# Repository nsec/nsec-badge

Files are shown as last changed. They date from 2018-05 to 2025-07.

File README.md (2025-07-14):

NorthSec 2025 badge
===================

Brought to you by the Team badge of NorthSec.

## Overview

<p align="center">
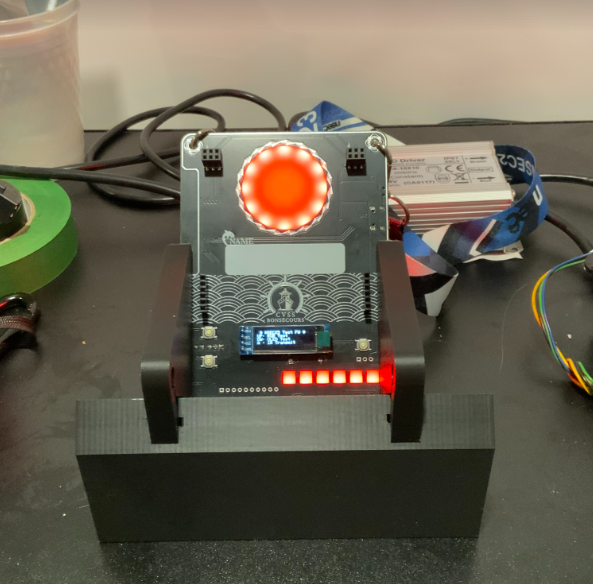
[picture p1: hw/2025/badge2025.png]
   <br>
</p>

## Hardware

The NorthSec 2025 badge is loosely based on the ESP32-C3 design with an
[ESP32-C3 microcontroller](https://www.espressif.com/en/products/socs/esp32-c3)
(ESP32-C3-WROOM-02-N4) which is used to drive several periphery devices:

- Eighteen [NeoPixel](https://en.wikipedia.org/wiki/Adafruit_Industries#NeoPixel) RGB LEDs
- Five buttons
- One IR 'pairing' connector
- Two [Shitty Add-On V1.69bis](https://hackaday.com/2019/03/20/introducing-the-shitty-add-on-v1-69bis-standard/) connector

The badge is powered through a USB-C port or through 3 AAA batteries.

If you wish to hack your badge or create a new one based on the hardware. All
the information [is available here](hw/2025/).

## Building the firmware

The firmware is based on the [Espressif IoT Development
Framework](https://docs.platformio.org/en/latest/frameworks/espidf.html). The
build system uses
[PlatformIO](https://docs.platformio.org/en/stable/what-is-platformio.html) to
easily manage the dependencies.

You can install it on Debian / Ubuntu in a python virtualenv with these
commands:

```bash
sudo apt install python3-virtualenv

virtualenv .venv
. .venv/bin/activate

pip install platformio
```

The installation procedure for your OS may differ a little, please consult the
[PlatformIO
documentation](https://docs.platformio.org/en/stable/core/installation/index.html)
if you have any difficulties.

Once the installation is complete you can build the firmware:

```bash
# Conference firmware
pio run -e conference

# CTF firmware
pio run -e ctf
```

## Flashing

Flash the firmware with this command:

```bash
# Conference firmware
pio run -t upload -e conference

# CTF firmware
pio run -t upload -e ctf
```

If multiple badges are connected, you can select which badge will be flash with
the `--upload-port <port_name>` option:

```bash
# Conference firmware
pio run -t upload -e conference --upload-port <port_name>
```

To improve the upload speed, you can skip the build validation/process with the
`-t nobuild` option:

```bash
# Conference firmware
pio run -t upload -t nobuild -e conference
```

## Debugging

To read the logging statements output on the USB serial interface, it is
possible to use `pio device monitor` or `idf.py`'s `monitor` command.

However, you can use your preferred terminal emulator by pointing it to the
`/dev/ttyACM0` device. The badge is configured to output at `115200` bauds,
without parity, and with one stop bit per character.

Note that electrically resetting the board using the hardware switch will cause
the pseudo-terminal device to disappear, making it hard to read the logs
emitted during boot.

Pulsing the DTR signal (lowering it for 1 second) will cause the board to reset
without affecting the pseudo-terminal device, allowing you to read early-boot
messages. This is supported by most terminal emulators.

## Credits
NorthSec CTF badge 2025 is brought to you by the teamwork of:

 - [abdelq](https://github.com/abdelq)
 - [IterateMe](https://github.com/IterateMe)
 - [lle](https://github.com/lle)
 - [nyx0](https://github.com/nyx0)
 - [p0ns](https://github.com/p0ns)
 - [padraignix](https://github.com/padraignix)
 - [Svieg](https://github.com/Svieg)
 - [sylemieux](https://github.com/sylemieux)
 - [TheKGBSpy](https://github.com/TheKGBSpy)
 - [mjeanson](https://github.com/mjeanson)

Special thanks to:
 - [20th](https://github.com/20th)
 - [jgalar](https://github.com/jgalar)

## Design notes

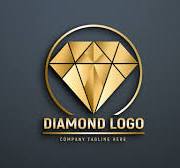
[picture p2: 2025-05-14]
hw/2025/sao/Sao_SlotMachine_v2/DiamondArt.jpg

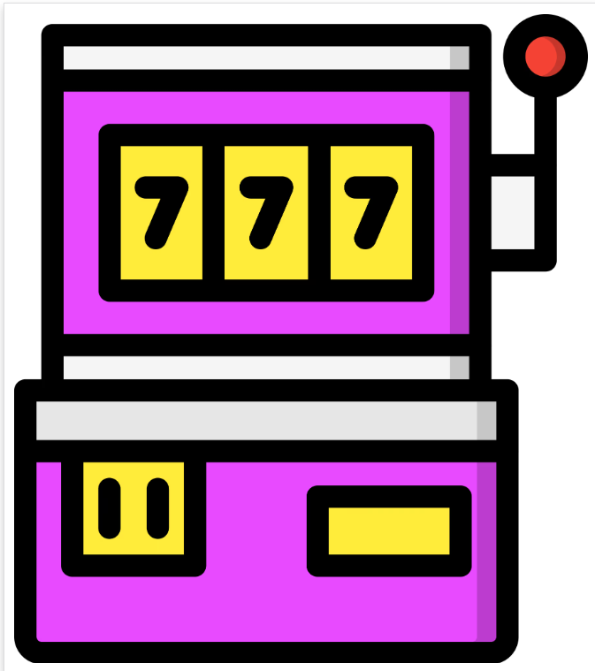
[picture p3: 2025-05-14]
hw/2025/sao/Sao_SlotMachine/image.png

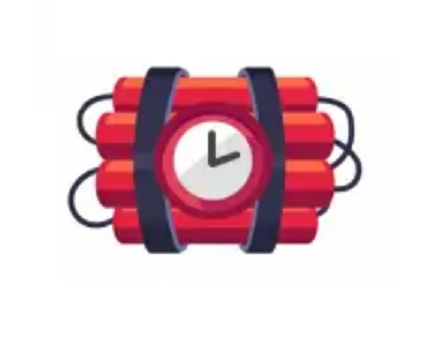
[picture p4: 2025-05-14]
hw/2025/sao/Sao_Bomb/Untitled.png

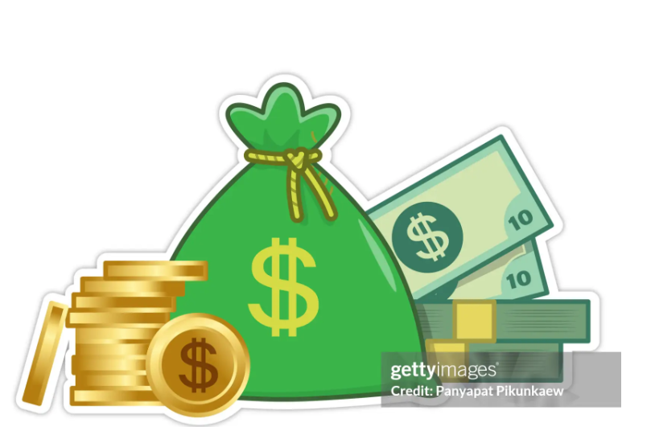
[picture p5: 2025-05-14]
hw/2025/sao/Sao_CashBag/Untitled.png

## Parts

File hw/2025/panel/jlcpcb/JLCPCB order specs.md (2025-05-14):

- Base Material: FR-4
- Layers: 2
- Dimensions: Auto
- Panel Qty: 5
- Product Type: Industrial/Consumer Electronics

## PCB Specifications
- Different design: 1
- Delivery format: Panel by Customer
- Panel Format: Column:2 Row:2 
- PCB Thickness: 1.6mm
- PCB Color: Black
- Silkscreen: White
- Surface Finish: ENIG
- Gold Thickness: 1 U''

## High-spec Options
- Outer Copper Weight: 1 oz
- Via Covering: Tented
- Min via hole size/diameter: 0.3mm/(0.4/0.45mm)
- Board Outline Tolerance: +-0.2mm(Regular)
- Confirm Production File: Yes
- Mark on PCB: 2D Barcode (Serial Number)
	- Printing: 2D barcode only
	- Code Type: Data Matrix Code
	- Serial Number Setting: 
		- Prefix: NSEC
		- Unique Number: leave as is
		- Incrementing number: 0001 (as is)
		- 2D barcode size: 5 * 5mm
		- 2D barcode position: Specify position
- Electrical Test: Flying Probe Fully Test
- Gold Fingers: Yes
- 30°finger chamfered: Yes
- Castellated Holes: No
- Edge Plating: No

## PCB Assembly
- PCBA Type: Standard
- Assembly Type: Both Sides
- PCBA Qty: 5
- Edge Rails/Fiducials: Added by Customer
- Confirm Parts Placement: yes
- Parts Selection: By Customer

## Advanced Options:
- Photo Confirmation: No
- Board Cleaning: No
- Conformal Coating: No
- Bake Components: No
- Packaging: Antistatic bubble film
- Depanel boards & edge rail before delivery: Yes
- Solder paste: Sn96.5%, Ag3.0%, Cu0.5%
- Add paste for unpopulated pad & step stencil opening: No
- Flying Probe Test: No
- Nitrogen Reflow Soldering: No
- Others: No

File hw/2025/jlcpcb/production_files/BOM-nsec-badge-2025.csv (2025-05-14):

Comment | Designator | Footprint | LCSC | Quantity
SSSS811101 | KEY1 | SW-SMD_SSSS811101 | C109335 | 1
MMBT3904 | Q1 | SOT-23 | C111113 | 1
MBR120LSF | D1,D2 | SOD-123_L2.8-W1.8-LS3.7-RD | C130880 | 2
0.1uF | C10,C11,C12,C13,C14,C15,C16,C20,C21,C22,C23,C24,C25,C5,C6,C7,C8,C9 | C_0603_1608Metric | C14663 | 18
1uF | C1,C17,C3,C4 | C_0603_1608Metric | C15849 | 4
10uF | C18,C2 | C_0805_2012Metric | C15850 | 2
TYPE-C-31-M-12 | U2 | USB-C_SMD-TYPE-C-31-M-12 | C165948 | 1
1K | R12 | R_0603_1608Metric | C21190 | 1
470 | R10 | R_0603_1608Metric | C23179 | 1
5.1K | R2,R3,R4,R5 | R_0603_1608Metric | C23186 | 4
56 | R11 | R_0603_1608Metric | C25196 | 1
100K | R1,R13 | R_0603_1608Metric | C25803 | 2
10K | R14,R6,R7,R8,R9 | R_0603_1608Metric | C25804 | 5
0.1uF | C19 | C_0805_2012Metric | C28233 | 1
ESP32-C3-WROOM-02-N4(4MB) | U1 | BULETM-SMD_ESPRESSIF_ESP32-C3-WROOM-02-N4-4MB | C2934560 | 1
TS-1187A-B-A-B | SW1,SW2,SW3,SW4 | SW-SMD_4P-L5.1-W5.1-P3.70-LS6.5-TL_H1.5 | C318884 | 4
PM254-2-03-S-8_5 | J1,J2 | HDR-SMD_6P-P2.54-V-F-R2-C3-LS7.0 | C3975148 | 2
Conn_01x06 | J6,J7 | PinSocket_1x06_P2.54mm_Vertical | C40877 | 2
TSOP34838 | U5 | SENSOR-TH_TSOP34838 | C44620 | 1
IR968-8C | U4 | LED-TH_L2.9-W2.9-P2.54-FD | C475375 | 1
AP2112K-3_3TRG1 | U6 | SOT-25-5_L2.9-W1.6-P0.95-LS2.8-BL | C51118 | 1
HS96L03W2C03 | U7 | OLED-TH_L38.0-W12.0_HS91L02W2C01 | C5248081 | 1
2479 | BT1 | BAT_2479 | C5370880 | 1
SK6812SIDE-A_C5378721 | RGB1,RGB10,RGB11,RGB12,RGB13,RGB14,RGB15,RGB16,RGB17,RGB18,RGB2,RGB3,RGB4,RGB5,RGB6,RGB7,RGB8,RGB9 | LED-SMD_SK6812SIDE-A_C5378721 | C5378721 | 18
TPSMF05CT1G | U3 | SOT-363_L2.0-W1.3-P0.65-LS2.1-BL | C558443 | 1
Fuse_Small | F1 | Fuse_1206_3216Metric_Pad1.42x1.75mm_HandSolder | C70065 | 1
FC-2012HRK-620D | LED1,LED2 | LED0805-R-RD | C84256 | 2

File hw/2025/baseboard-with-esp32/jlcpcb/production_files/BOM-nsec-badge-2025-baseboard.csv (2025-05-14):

Comment | Designator | Footprint | LCSC | Quantity
SSSS811101 | KEY1,KEY2 | SW-SMD_SSSS811101 | C109335 | 2
MBR120LSF | D1,D2,D3,D5 | SOD-123_L2.8-W1.8-LS3.7-RD | C130880 | 4
XT4054K421MR-G | U8 | SOT-23-5_L3.0-W1.7-P0.95-LS2.8-BL | C141405 | 1
0.1uF | C5 | C_0603_1608Metric | C14663 | 1
1uF | C1,C3,C6,C9 | C_0603_1608Metric | C15849 | 4
10uF | C2,C4,C8 | C_0805_2012Metric | C15850 | 3
TYPE-C-31-M-12 | U3 | USB-C_SMD-TYPE-C-31-M-12 | C165948 | 1
4.7uF | C7 | C_0805_2012Metric | C1779 | 1
1K | R12,R7,R8,R9 | R_0603_1608Metric | C21190 | 4
WS2812B | D4 | LED_WS2812B_PLCC4_5.0x5.0mm_P3.2mm | C22461793 | 1
390K | R10 | R_0603_1608Metric | C23150 | 1
5.1K | R1,R3,R4,R5 | R_0603_1608Metric | C23186 | 4
100K | R11,R2 | R_0603_1608Metric | C25803 | 2
10K | R6 | R_0603_1608Metric | C25804 | 1
Bus_PCI_32bit_Universal | J5 | CONN-TH_EH06003-DAW-DF | C2761459 | 1
LTST-S220KRKT | LED1,LED2,LED3,LED4 | LED-SMD_L2.2-W1.0-RD_RED-SIDE | C284935 | 4
ESP32-S3-WROOM-1 | U1 | ESP32-S3-WROOM-1 | C2913204 | 1
AP2112K-3_3TRG1 | U2 | SOT-25-5_L2.9-W1.6-P0.95-LS2.8-BL | C51118 | 1
TPSMF05CT1G | U4 | SOT-363_L2.0-W1.3-P0.65-LS2.1-BL | C558443 | 1
XDWF-0920-02P | U7 | CONN-SMD_XDWF-0920-02P | C7527581 | 1
K2-1102SP-Z4SC-04 | U9 | KEY-SMD_4P-L6.0-W6.0-P4.50-LS9.0 | C879736 | 1
GT-TC018A-H0375-L1 | U5,U6 | SW-SMD_L4.7-W3.5-P3.35-EH | C963235 | 2

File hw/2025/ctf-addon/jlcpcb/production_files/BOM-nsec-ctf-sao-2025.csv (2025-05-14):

Comment | Designator | Footprint | LCSC | Quantity
MMBT3906 | U1 | SOT-23-3_L3.0-W1.7-P0.95-LS2.9-BR | C111114 | 1
MBR120LSF | D10 | SOD-123_L2.8-W1.8-LS3.7-RD | C130880 | 1
1 | R6 | R_1206_3216Metric_Pad1.30x1.75mm_HandSolder | C1409 | 1
10K | R10,R9 | R_0805_2012Metric_Pad1.20x1.40mm_HandSolder | C17414 | 2
75 | R1,R2,R3,R4,R5,R7,R8 | R_1206_3216Metric_Pad1.30x1.75mm_HandSolder | C17987 | 7
LED | D1,D2,D3,D4,D5,D6,D7,D8 | LED_1206_3216Metric_Pad1.42x1.75mm_HandSolder | C965822 | 8

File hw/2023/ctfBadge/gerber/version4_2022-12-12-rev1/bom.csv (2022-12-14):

Qty | Value | Device | Package | Parts | JLCPCB | DIGIKEY
22 | 0.1uF | C-EUC0603 | C0603 | C1, C2, C3, C4, C5, C6, C7, C9, C10, C11, C12, C13, C14, C15, C16, C17, C19, C20, C21, C22, C23, C24 | C14663
3 | 100K | RESISTOR_0603_NOOUT | 0603-NO | R1, R3, R7 | C25803
3 | 10201020_KEY | 10201020_KEY | 1020_KEY | U27, U28, U29 |  | 36-1020-ND
3 | 10K | RESISTOR_0603_NOOUT | 0603-NO | R5, R6, R8 | C25804
2 | 10uF | CAP_CERAMIC0805-NOOUTLINE | 0805-NO | C27, C30 | C440198
3 | 1K | RESISTOR_0603_NOOUT | 0603-NO | R10, R13, R14 | C21190
3 | 1uF | CAP_CERAMIC0603_NO | 0603-NO | C8, C26, C31 | C15849
2 | 470 | RESISTOR_0603_NOOUT | 0603-NO | R9, R11 | C114669
2 | 5.1K | RESISTOR_0603_NOOUT | 0603-NO | R2, R4 | C23186
1 | AP2112-3.3 | VREG_SOT23-5 | SOT23-5 | U2 | C150742
1 | CH340C | CH340C | SOIC127P600X180-16N | U1 | C84681
1 | ESP32_WROOM32_SKINNY | ESP32_WROOM32_SKINNY | WROOM32_SKINNY | X2 | C82899
1 | KMR2 | SWITCH_TACT_SMT4.6X2.8 | BTN_KMR2_4.6X2.8 | SW2 | C269272
2 | MBR120 | DIODE-SCHOTTKYSOD-123 | SOD-123 | D2, D6 | C130880
1 | PCM12SMTRPCM12SMTR_CNK | PCM12SMTRPCM12SMTR_CNK | PCM12SMTR_CNK | U5 |  | 401-2016-2-ND
3 | RED | LED0805_NOOUTLINE | CHIPLED_0805_NOOUTLINE | D1, D3, D5 | C84256
1 | SMF05CT1G | SMF05CT1G | SOT65P210X110-6N | U4 | C558443
1 | SSW-103-22-F-D-VS-K-TRCON3_SSW-D-DUMZ_HDR_SAI | SSW-103-22-F-D-VS-K-TRCON3_SSW-D-DUMZ_HDR_SAI | CON3_SSW-D-DUMZ_HDR_SAI | J2 |  | 952-3251-ND
1 | TYPE-C-31-M-12 | TYPE-C-31-M-12 | HRO_TYPE-C-31-M-12 | J3 | C165948
21 | WS2812-2020 | WS2812-2020 | LED_WS2812-2020 | U6, U7, U8, U9, U10, U11, U12, U13, U14, U15, U16, U17, U18, U19, U20, U21, U22, U23, U24, U25, U26 | C965555
2 | mmbt2222 | TRANSISTOR_NPNSOT23-3 | SOT23-3 | Q1, Q2 | C8512

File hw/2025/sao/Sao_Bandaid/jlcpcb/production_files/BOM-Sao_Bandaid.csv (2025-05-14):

Comment | Designator | Footprint | LCSC | Quantity
SAO Connector SMD | J1 | SAO Connector SMD |  | 1
1K | R3 | R_1206_3216Metric_Pad1.30x1.75mm_HandSolder |  | 1
1K | R2 | R_1206_3216Metric_Pad1.30x1.75mm_HandSolder |  | 1
330 | R1 | R_1206_3216Metric_Pad1.30x1.75mm_HandSolder |  | 1
LED | D1 | LED_1206_3216Metric_Pad1.42x1.75mm_HandSolder |  | 1

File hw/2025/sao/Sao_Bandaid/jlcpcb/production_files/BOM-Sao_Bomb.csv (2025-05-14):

Comment | Designator | Footprint | LCSC | Quantity
330 | R4 | R_1206_3216Metric_Pad1.30x1.75mm_HandSolder |  | 1
330 | R2 | R_1206_3216Metric_Pad1.30x1.75mm_HandSolder |  | 1
330 | R3 | R_1206_3216Metric_Pad1.30x1.75mm_HandSolder |  | 1
330 | R1 | R_1206_3216Metric_Pad1.30x1.75mm_HandSolder |  | 1
LED | D3 | LED_1206_3216Metric_Pad1.42x1.75mm_HandSolder |  | 1
LED | D4 | LED_1206_3216Metric_Pad1.42x1.75mm_HandSolder |  | 1
LED | D1 | LED_1206_3216Metric_Pad1.42x1.75mm_HandSolder |  | 1
LED | D2 | LED_1206_3216Metric_Pad1.42x1.75mm_HandSolder |  | 1
Conn_01x01_Socket |  | PinSocket_1x01_P1.27mm_Vertical |  | 0
Conn_01x01_Socket |  | PinSocket_1x01_P1.27mm_Vertical |  | 0
Conn_01x01_Socket |  | PinSocket_1x01_P1.27mm_Vertical |  | 0
Conn_01x01_Socket |  | PinSocket_1x01_P1.27mm_Vertical |  | 0
Conn_01x01_Socket |  | PinSocket_1x01_P1.27mm_Vertical |  | 0
Conn_01x01_Socket |  | PinSocket_1x01_P1.27mm_Vertical |  | 0
Conn_01x01_Socket |  | PinSocket_1x01_P1.27mm_Vertical |  | 0
Conn_01x01_Socket |  | PinSocket_1x01_P1.27mm_Vertical |  | 0
SAO Connector SMD | J1 | SAO Connector SMD |  | 1

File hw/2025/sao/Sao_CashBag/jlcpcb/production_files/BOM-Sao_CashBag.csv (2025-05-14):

Comment | Designator | Footprint | LCSC | Quantity
LED | D2 | LED_1206_3216Metric_Pad1.42x1.75mm_HandSolder |  | 1
LED | D3 | LED_1206_3216Metric_Pad1.42x1.75mm_HandSolder |  | 1
LED | D1 | LED_1206_3216Metric_Pad1.42x1.75mm_HandSolder |  | 1
330 | R1 | R_1206_3216Metric_Pad1.30x1.75mm_HandSolder |  | 1
330 | R2 | R_1206_3216Metric_Pad1.30x1.75mm_HandSolder |  | 1
330 | R3 | R_1206_3216Metric_Pad1.30x1.75mm_HandSolder |  | 1
SAO Connector SMD | J1 | SAO Connector SMD |  | 1

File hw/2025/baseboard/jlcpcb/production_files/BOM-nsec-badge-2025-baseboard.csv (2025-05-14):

Comment | Designator | Footprint | LCSC | Quantity
Bus_PCI_32bit_Universal | J5 | CONN-TH_EH06003-DAW-DF | C2761459 | 1
Conn_01x02_Socket |  | PinSocket_1x02_P2.54mm_Vertical |  | 0
Conn_01x15_Socket |  | PinSocket_1x15_P2.54mm_Vertical |  | 0
Conn_01x02_Socket |  | PinSocket_1x02_P2.54mm_Vertical |  | 0
Conn_01x02_Socket |  | PinSocket_1x02_P2.54mm_Vertical |  | 0
Conn_01x08_Socket |  | PinHeader_1x08_P2.54mm_Vertical |  | 0
Conn_01x02_Socket |  | PinSocket_1x02_P2.54mm_Vertical |  | 0

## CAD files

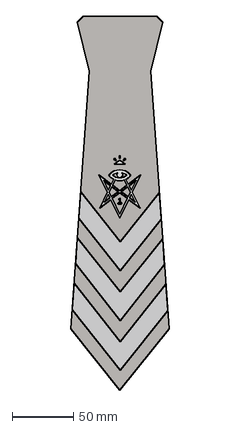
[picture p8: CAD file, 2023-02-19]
hw/2023/ctfBadge/design/badgeCTF2023-01.dxf
79.9 x 304.7 mm

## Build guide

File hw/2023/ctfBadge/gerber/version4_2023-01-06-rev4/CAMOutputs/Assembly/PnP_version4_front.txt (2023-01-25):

C1	-29.00	-230.00	270.00	0.1uF	C0603
C10	27.00	-210.00	270.00	0.1uF	C0603
C11	-23.00	-256.00	270.00	0.1uF	C0603
C12	-27.00	-210.00	270.00	0.1uF	C0603
C13	23.00	-256.00	270.00	0.1uF	C0603
C14	25.00	-190.00	270.00	0.1uF	C0603
C15	-25.00	-190.00	270.00	0.1uF	C0603
C16	23.00	-170.00	270.00	0.1uF	C0603
C17	-22.00	-170.00	270.00	0.1uF	C0603
C19	21.00	-150.00	270.00	0.1uF	C0603
C2	-17.00	-110.00	270.00	0.1uF	C0603
C20	-19.50	-150.00	270.00	0.1uF	C0603
C21	19.00	-130.00	270.00	0.1uF	C0603
C22	-18.00	-130.00	270.00	0.1uF	C0603
C23	0.00	-292.00	0.00	0.1uF	C0603
C24	17.00	-110.00	270.00	0.1uF	C0603
C26	-16.51	-19.69	0.00	1uF	0603-NO
C27	-11.43	-20.96	180.00	10uF	0805-NO
C3	15.00	-90.00	270.00	0.1uF	C0603
C30	-10.79	-3.81	90.00	10uF	0805-NO
C31	-4.45	-36.83	270.00	1uF	0603-NO
C4	-15.00	-90.00	270.00	0.1uF	C0603
C5	14.00	-70.00	270.00	0.1uF	C0603
C6	29.00	-230.00	270.00	0.1uF	C0603
C7	-14.00	-70.00	270.00	0.1uF	C0603
C8	-11.43	-16.51	90.00	1uF	0603-NO
C9	8.89	-26.67	90.00	0.1uF	C0603
D1	-15.88	-5.08	90.00	RED	CHIPLED_0805_NOOUTLINE
D2	-13.97	-25.40	270.00	MBR120	SOD-123
D3	-5.71	-24.77	0.00	RED	CHIPLED_0805_NOOUTLINE
D5	-13.34	-36.83	90.00	RED	CHIPLED_0805_NOOUTLINE
D6	-16.51	-25.40	270.00	MBR120	SOD-123
J2	0.64	-62.23	210.00	SSW-103-22-F-D-VS-K-TRCON3_SSW-D-DUMZ_HDR_SAI	CON3_SSW-D-DUMZ_HDR_SAI
J3	-18.89	-31.24	284.00	TYPE-C-31-M-12	HRO_TYPE-C-31-M-12
Q1	21.54	-34.93	90.00	mmbt2222	SOT23-3
Q2	22.28	-30.48	270.00	mmbt2222	SOT23-3
R1	-10.79	-10.16	180.00	100K	0603-NO
R10	-3.81	-24.77	270.00	1K	0603-NO
R11	12.70	-6.99	0.00	470	0603-NO
R13	-17.14	-38.10	180.00	5.1K	0603-NO
R14	-15.88	-3.18	0.00	5.1K	0603-NO
R2	-13.34	-34.93	0.00	5.1K	0603-NO
R3	-10.79	-12.07	0.00	100K	0603-NO
R4	-13.34	-33.02	0.00	5.1K	0603-NO
R5	17.14	-33.02	180.00	10K	0603-NO
R6	17.14	-36.20	0.00	10K	0603-NO
R7	-13.34	-16.51	270.00	100K	0603-NO
R8	17.14	-38.10	0.00	10K	0603-NO
R9	12.70	-8.89	0.00	470	0603-NO
SW2	0.00	-36.83	180.00	KMR2	BTN_KMR2_4.6X2.8
U1	8.89	-33.02	270.00	CH340C	SOIC127P600X180-16N
U10	-22.00	-110.00	180.00	WS2812-2020	LED_WS2812-2020
U11	22.00	-110.00	180.00	WS2812-2020	LED_WS2812-2020
U12	-24.00	-130.00	180.00	WS2812-2020	LED_WS2812-2020
U13	24.00	-130.00	180.00	WS2812-2020	LED_WS2812-2020
U14	-26.00	-150.00	180.00	WS2812-2020	LED_WS2812-2020
U15	26.00	-150.00	180.00	WS2812-2020	LED_WS2812-2020
U16	-28.00	-170.00	180.00	WS2812-2020	LED_WS2812-2020
U17	28.00	-170.00	180.00	WS2812-2020	LED_WS2812-2020
U18	-30.00	-190.00	180.00	WS2812-2020	LED_WS2812-2020
U19	30.00	-190.00	180.00	WS2812-2020	LED_WS2812-2020
U2	-16.51	-16.51	90.00	AP2112-3.3	SOT23-5
U20	-32.00	-210.00	180.00	WS2812-2020	LED_WS2812-2020
U21	32.00	-210.00	180.00	WS2812-2020	LED_WS2812-2020
U22	-34.00	-230.00	180.00	WS2812-2020	LED_WS2812-2020
U23	34.00	-230.00	180.00	WS2812-2020	LED_WS2812-2020
U24	-28.00	-256.00	180.00	WS2812-2020	LED_WS2812-2020
U25	28.00	-256.00	180.00	WS2812-2020	LED_WS2812-2020
U26	0.00	-287.00	180.00	WS2812-2020	LED_WS2812-2020
U4	17.14	-30.48	180.00	SMF05CT1G	SOT65P210X110-6N
U6	-18.00	-70.00	180.00	WS2812-2020	LED_WS2812-2020
U7	18.00	-70.00	180.00	WS2812-2020	LED_WS2812-2020
U8	-20.00	-90.00	180.00	WS2812-2020	LED_WS2812-2020
U9	20.00	-90.00	180.00	WS2812-2020	LED_WS2812-2020
X2	0.36	-11.71	0.00	ESP32_WROOM32_SKINNY	WROOM32_SKINNY

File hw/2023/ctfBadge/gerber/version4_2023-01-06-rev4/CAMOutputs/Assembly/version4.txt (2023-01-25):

Partlist exported from C:/Users/lambert/Documents/GitHub/nsec-badge-dev/hw/2023/ctfBadge/version4.sch at 2023-01-06 4:14 PM

Qty Value                                         Device                                        Package                 Parts                                                                                                Description                                                                              AVAILABILITY COPYRIGHT                                                DESCRIPTION                                                                DIGI-KEY_PART_NUMBER_1 DIGI-KEY_PART_NUMBER_2 DIGI-KEY_PART_NUMBER_3 DIGI-KEY_PART_NUMBER_4 DIGI-KEY_PART_NUMBER_5 MANUFACTURER              MANUFACTURER_PART_NUMBER MAXIMUM_PACKAGE_HEIGHT MF               MFR_NAME             MP          PACKAGE                  PARTREV    POPULARITY PRICE PURCHASE-URL                                               SNAPEDA_PN     STANDARD                     TP_SIGNAL_NAME
22  0.1uF                                         C-EUC0603                                     C0603                   C1, C2, C3, C4, C5, C6, C7, C9, C10, C11, C12, C13, C14, C15, C16, C17, C19, C20, C21, C22, C23, C24 CAPACITOR, European symbol                                                                                                                                                                                                                                                                                                                                                                                                                                                                                                                                                                                                                                         
3   100K                                          RESISTOR_0603_NOOUT                           0603-NO                 R1, R3, R7                                                                                           Resistors                                                                                                                                                                                                                                                                                                                                                                                                                                                                                                                                                                                                                                                          
3   10201020_KEY                                  10201020_KEY                                  1020_KEY                U27, U28, U29                                                                                                                                                                                              Copyright (C) 2022 Ultra Librarian. All rights reserved.                                                                            1020K-ND               1528-2635-ND           290-1966-ND            2991-1020-ND           36-1020-ND                                       1020                                                             Keystone Electronics                                                                                                                                                                                       
3   10K                                           RESISTOR_0603_NOOUT                           0603-NO                 R5, R6, R8                                                                                           Resistors                                                                                                                                                                                                                                                                                                                                                                                                                                                                                                                                                                                                                                                          
2   10uF                                          CAP_CERAMIC0805-NOOUTLINE                     0805-NO                 C27, C30                                                                                             Ceramic Capacitors                                                                                                                                                                                                                                                                                                                                                                                                                                                                                                                                                                                                                                                 
1   1K                                            RESISTOR_0603_NOOUT                           0603-NO                 R10                                                                                                  Resistors                                                                                                                                                                                                                                                                                                                                                                                                                                                                                                                                                                                                                                                          
3   1uF                                           CAP_CERAMIC0603_NO                            0603-NO                 C8, C26, C31                                                                                         Ceramic Capacitors                                                                                                                                                                                                                                                                                                                                                                                                                                                                                                                                                                                                                                                 
2   470                                           RESISTOR_0603_NOOUT                           0603-NO                 R9, R11                                                                                              Resistors                                                                                                                                                                                                                                                                                                                                                                                                                                                                                                                                                                                                                                                          
4   5.1K                                          RESISTOR_0603_NOOUT                           0603-NO                 R2, R4, R13, R14                                                                                     Resistors                                                                                                                                                                                                                                                                                                                                                                                                                                                                                                                                                                                                                                                          
1   AP2112-3.3                                    VREG_SOT23-5                                  SOT23-5                 U2                                                                                                   SOT23-5 Fixed Voltage Regulators                                                                                                                                                                                                                                                                                                                                                                                                                                                                                                                                                                                                                                   
1   CH340C                                        CH340C                                        SOIC127P600X180-16N     U1                                                                                                   USB to serial chip CH340    Check prices                                                 Not in stock                                                           USB to serial chip CH340                                                                                                                                                                                                                                               WCH                                   CH340C      None                                           None                                                                                                                       
1   ESP32_WROOM32_SKINNY                          ESP32_WROOM32_SKINNY                          WROOM32_SKINNY          X2                                                                                                                                                                                                                                                                                                                                                                                                                                                                                                                                                                                                                                                                                                                                                                      
1   KMR2                                          SWITCH_TACT_SMT4.6X2.8                        BTN_KMR2_4.6X2.8        SW2                                                                                                  SMT Tact Switches                                                                                                                                                                                                                                                                                                                                                                                                                                                                                                                                                                                                                                                  
2   MBR120                                        DIODE-SCHOTTKYSOD-123                         SOD-123                 D2, D6                                                                                                                                                                                                                                                                                                                                                                                                                                                                                                                                                                                                                                                                                                                                                                  
1   PCM12SMTRPCM12SMTR_CNK                        PCM12SMTRPCM12SMTR_CNK                        PCM12SMTR_CNK           U5                                                                                                                                                                                                         Copyright (C) 2022 Ultra Librarian. All rights reserved.                                                                            401-2016-2-ND          401-2016-1-ND          401-2016-6-ND          2266-PCM12SMTR-ND                                                       PCM12SMTR                                                        C&K                                                                                                                                                                                                        
4   PTR1B1,27                                     PTR1B1,27                                     B1,27                   TP1, TP2, TP3, TP4                                                                                   TEST PIN                                                                                                                                                                                                                                                                                                                                                                                                                                                                                                                     2                                                                                                                                     
3   RED                                           LED0805_NOOUTLINE                             CHIPLED_0805_NOOUTLINE  D1, D3, D5                                                                                           LED                                                                                                                                                                                                                                                                                                                                                                                                                                                                                                                                                                                                                                                                
1   SMF05CT1G                                     SMF05CT1G                                     SOT65P210X110-6N        U4                                                                                                   SMF05C Series 7.2 V 100 W 5-Line Transient Voltage Suppressor Array - SC-88 Check prices In Stock                                                               12.5V Clamp 8A (8/20µs) Ipp Tvs Diode Surface Mount SC-88/SC70-6/SOT-363                                                                                                                                                                                               ON Semiconductor                      SMF05CT1G   SC-88-6 ON Semiconductor                       None  https://pricing.snapeda.com/search/part/SMF05CT1G/?ref=eda                                                           
1   SSW-103-22-F-D-VS-K-TRCON3_SSW-D-DUMZ_HDR_SAI SSW-103-22-F-D-VS-K-TRCON3_SSW-D-DUMZ_HDR_SAI CON3_SSW-D-DUMZ_HDR_SAI J2                                                                                                                                                                                                         Copyright (C) 2022 Ultra Librarian. All rights reserved.                                                                            SAM14622CT-ND          SAM14622DKR-ND         SAM14622TR-ND                                                                                  SSW-103-22-F-D-VS-K-TR                                           Samtec Inc                                                                                                                                                                                                 
1   TYPE-C-31-M-12                                TYPE-C-31-M-12                                HRO_TYPE-C-31-M-12      J3                                                                                                                                                                                                                                                                                                                                                                                                                                                                HRO Electronics Co., Ltd.                          3.26 mm                                                                                           2020.12.08                                                                             TYPE-C-31-M-12 Manufacturer Recommendations               
21  WS2812-2020                                   WS2812-2020                                   LED_WS2812-2020         U6, U7, U8, U9, U10, U11, U12, U13, U14, U15, U16, U17, U18, U19, U20, U21, U22, U23, U24, U25, U26  Intelligent control LED                                                                  Not in stock                                                           Intelligent control LED light source, SMD-4                                                                                                                                                                                                                            Worldsemi                             WS2812-2020 Package                                        None                                                                                                                       
2   mmbt2222                                      TRANSISTOR_NPNSOT23-3                         SOT23-3                 Q1, Q2                                                                                               Transistor NPN

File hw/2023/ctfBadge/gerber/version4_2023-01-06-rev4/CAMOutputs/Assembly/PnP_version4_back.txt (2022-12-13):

TP1	17.14	-13.97	0.00	PTR1B1,27	B1,27
TP2	17.14	-12.07	0.00	PTR1B1,27	B1,27
TP3	17.14	-10.16	0.00	PTR1B1,27	B1,27
TP4	17.14	-8.26	0.00	PTR1B1,27	B1,27
U27	-15.24	-237.49	270.00	10201020_KEY	1020_KEY
U28	0.00	-237.49	90.00	10201020_KEY	1020_KEY
U29	15.24	-237.49	270.00	10201020_KEY	1020_KEY
U5	-23.25	-57.53	185.00	PCM12SMTRPCM12SMTR_CNK	PCM12SMTR_CNK

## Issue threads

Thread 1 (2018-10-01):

Leak

obilodeau, 2018-10-01:
https://github.com/nsec/nsec-badge/blob/7a2f7601874b1e2cf20599a2e3ec0ffa3dc4f5e5/nrf52/led_code_storage.h#L45

:open_mouth:

marc-etienne, 2018-10-01:
nsec18 is finished
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

cashew22, 2018-10-01:
Hahahahaa

Closed 2018-10-01.

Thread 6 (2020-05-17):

Leak 2019

obilodeau, 2020-05-17:
https://github.com/nsec/nsec-badge/blob/715ede438ac93091a8bc02fcf55e7b89646ac012/nrf52/include/led_code_storage.h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

:open_mouth:

simark, 2020-05-17:
Hmm yes?

obilodeau, 2020-05-17:
Related to #1

Closed 2020-05-27.

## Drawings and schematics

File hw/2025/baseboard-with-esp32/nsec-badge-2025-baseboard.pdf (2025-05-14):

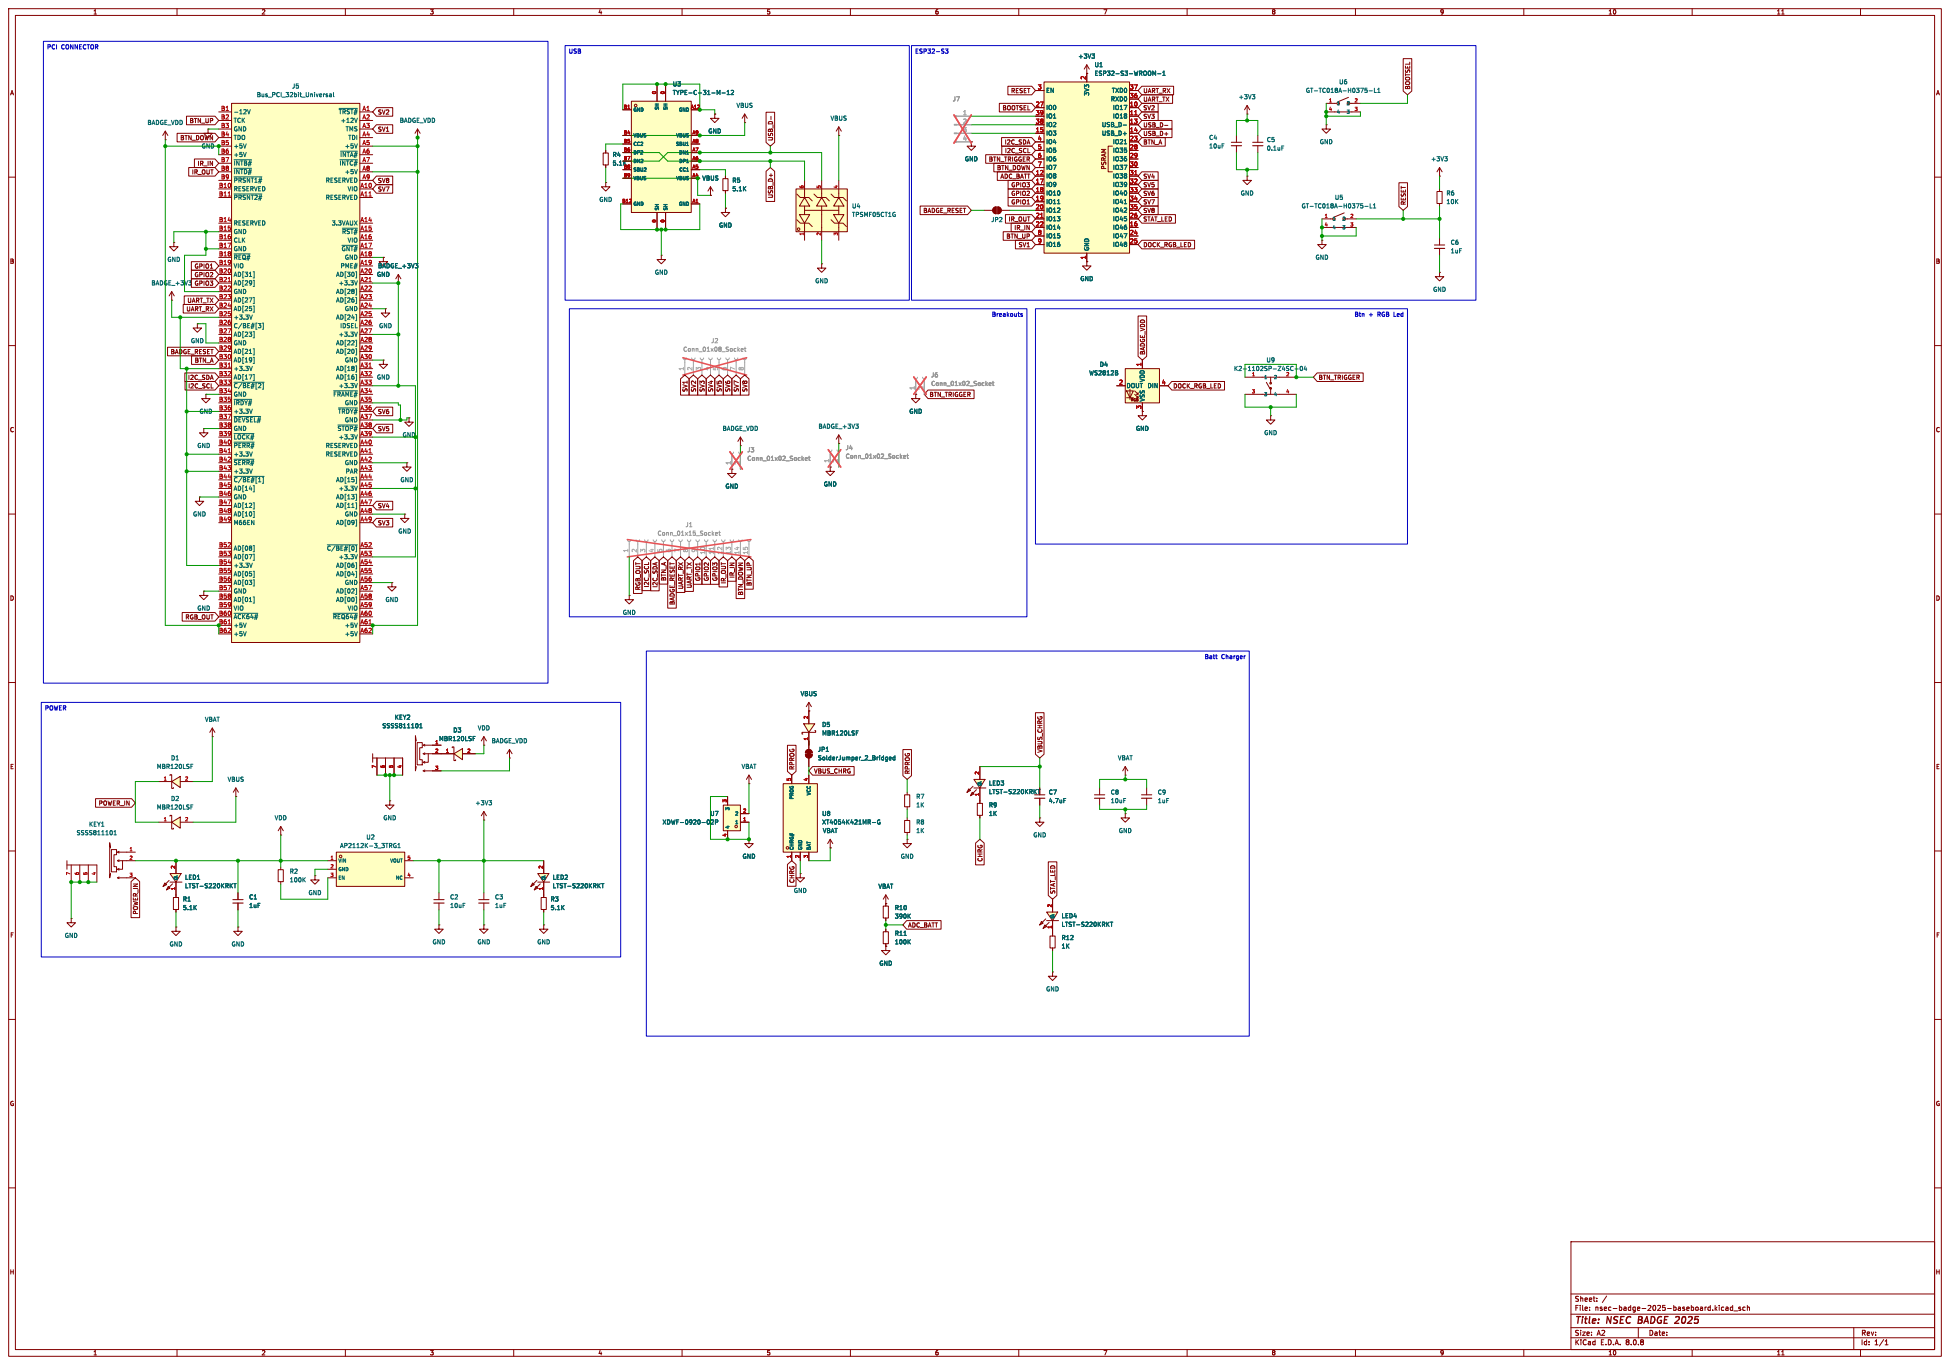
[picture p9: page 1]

Btn + RGB Led PCI CONNECTOR

J5 Bus_PCI_32bit_Universal BADGE_VDD GND
-12V B1 RESERVED B10 ~{PRSNT2#} B11 RESERVED B14 GND B15 CLK B16 GND B17 ~{REQ#} B18 VIO B19 TCK B2 AD[31] B20 AD[29] B21 GND B22 AD[27] B23 AD[25] B24 +3.3V B25 C/BE#[3] B26 AD[23] B27 GND B28 AD[21] B29 GND B3 AD[19] B30 +3.3V B31 AD[17] B32 ~{C/BE#[2]} B33 GND B34 ~{IRDY#} B35 +3.3V B36 ~{DEVSEL#} B37 GND B38 ~{LOCK#} B39
3.3VAUX A14 ~{RST#}A15 VIO A16 ~{GNT#}A17 GND A18 PME# A19 +12V A2 AD[30] A20 +3.3V A21 AD[28] A22 AD[26] A23 GND A24 AD[24] A25
BADGE_VDD GND
IDSEL A26 +3.3V A27 AD[22] A28 AD[20] A29 TMS A3 GND A30 AD[18] A31 AD[16] A32 +3.3V A33 ~{FRAME#}A34 GND A35 ~{TRDY#}A36 GND A37 ~{STOP#}A38 +3.3V A39

0 GND A1 GND A12 VBUS A4 CC1 A5 DP1 A6 DN1 A7 SBU1 A8 VBUS A9 GND B1 GND B12 VBUS B4 CC2 B5 DP2 B6 DN2 B7 SBU2 B8 VBUS B9 U3 TYPE-C-31-M-12 GND

TDI A4 RESERVED A40 RESERVED A41 GND A42 PAR A43 AD[15] A44 +3.3V A45 AD[13] A46 AD[11] A47 GND A48 AD[09] A49

0 GND A1 GND A12 VBUS A4 CC1 A5 DP1 A6 DN1 A7 SBU1 A8 VBUS A9 GND B1 GND B12 VBUS B4 CC2 B5 DP2 B6 DN2 B7 SBU2 B8 VBUS B9 GND GND

BTN_UP UART_RX
TDO B4 ~{PERR#} B40 +3.3V B41 ~{SERR#} B42 +3.3V B43 ~{C/BE#[1]} B44 AD[14] B45 GND B46 AD[12] B47 AD[10] B48 M66EN B49
+5V B5 AD[08] B52 AD[07] B53 +3.3V B54 AD[05] B55 AD[03] B56 GND B57 AD[01] B58 VIO B59
GND
~{INTB#} B7 ~{INTD#} B8 ~{PRSNT1#} B9

~{C/BE#[0]} A52 +3.3V A53 AD[06] A54 AD[04] A55 GND A56 AD[02] A57 AD[00] A58 VIO A59

File: nsec-badge-2025-baseboard.kicad_sch Sheet: /

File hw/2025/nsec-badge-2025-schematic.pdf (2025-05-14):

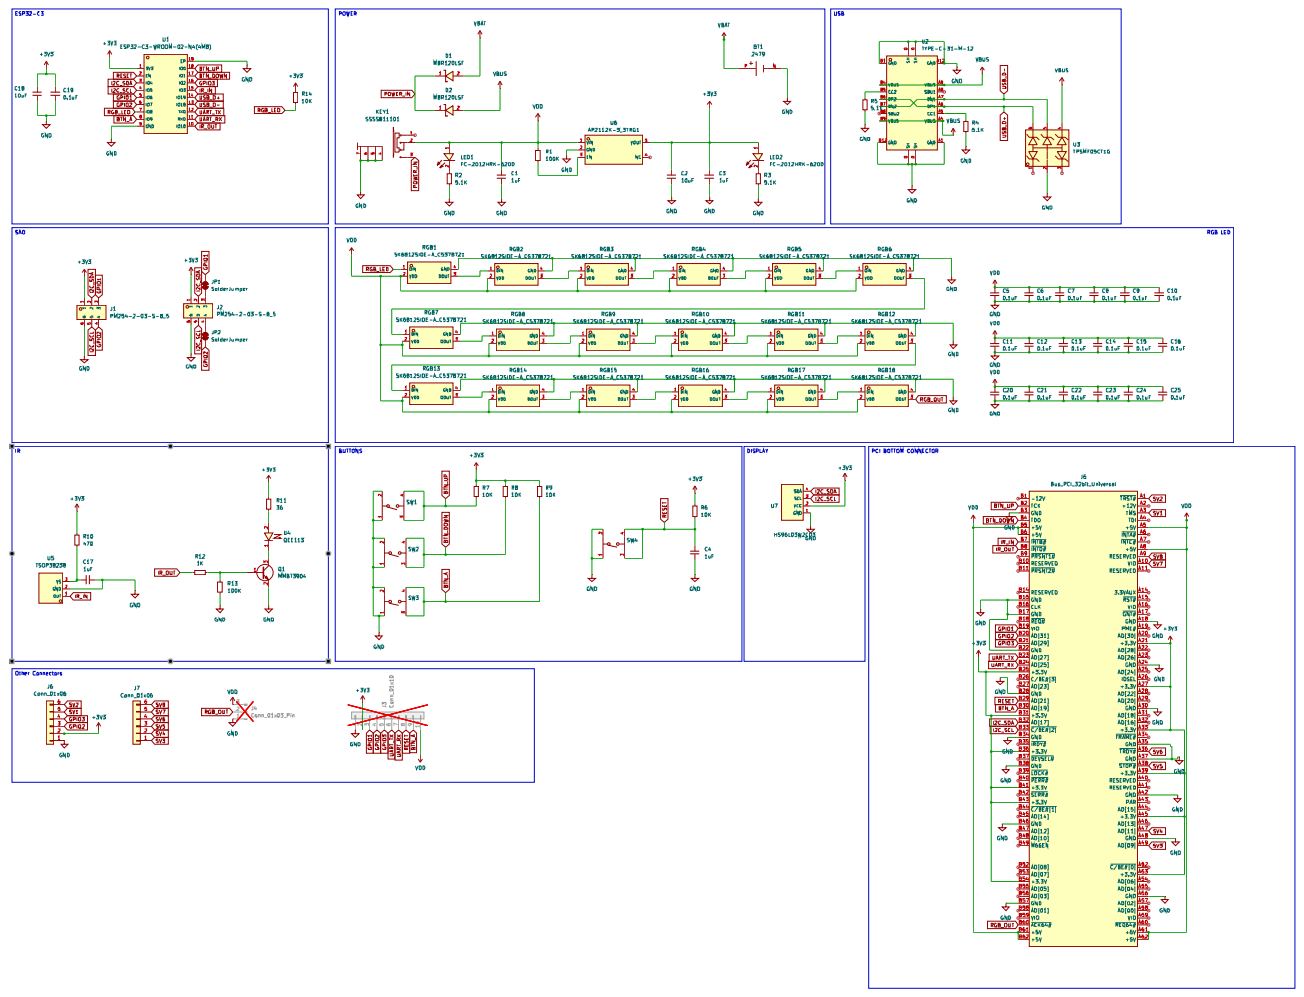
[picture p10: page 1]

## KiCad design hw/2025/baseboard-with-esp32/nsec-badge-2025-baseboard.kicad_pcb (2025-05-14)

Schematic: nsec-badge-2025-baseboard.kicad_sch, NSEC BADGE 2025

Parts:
C1, C3, C6, C9: 1uF; C_0603_1608Metric; LCSC C15849
C2, C4, C8: 10uF; C_0805_2012Metric; LCSC C15850
C5: 0.1uF; C_0603_1608Metric; LCSC C14663
C7: 4.7uF; C_0805_2012Metric; LCSC C1779
D1, D2, D3, D5: MBR120LSF; SOD-123_L2.8-W1.8-LS3.7-RD; LCSC C130880
D4: WS2812B; LED_WS2812B_PLCC4_5.0x5.0mm_P3.2mm; LCSC C22461793
J1: Conn_01x15_Socket; PinSocket_1x15_P2.54mm_Vertical; not fitted
J2: Conn_01x08_Socket; PinHeader_1x08_P2.54mm_Vertical; not fitted
J3, J4, J6: Conn_01x02_Socket; PinSocket_1x02_P2.54mm_Vertical; not fitted
J5: Bus_PCI_32bit_Universal; CONN-TH_EH06003-DAW-DF; LCSC C2761459
J7: Conn_01x04_Pin; PinHeader_1x04_P1.27mm_Vertical; not fitted
JP1: SolderJumper_2_Bridged; SolderJumper-2_P1.3mm_Bridged_RoundedPad1.0x1.5mm
JP2: SolderJumper_2_Open; SolderJumper-2_P1.3mm_Open_RoundedPad1.0x1.5mm
KEY1, KEY2: SSSS811101; SW-SMD_SSSS811101; LCSC C109335
LED1, LED2, LED3, LED4: LTST-S220KRKT; LED-SMD_L2.2-W1.0-RD_RED-SIDE; LCSC C284935
R1, R3, R4, R5: 5.1K; R_0603_1608Metric; LCSC C23186
R2, R11: 100K; R_0603_1608Metric; LCSC C25803
R6: 10K; R_0603_1608Metric; LCSC C25804
R7, R8, R9, R12: 1K; R_0603_1608Metric; LCSC C21190
R10: 390K; R_0603_1608Metric; LCSC C23150
U1: ESP32-S3-WROOM-1; LCSC C2913204
U2: AP2112K-3_3TRG1; SOT-25-5_L2.9-W1.6-P0.95-LS2.8-BL; LCSC C51118
U3: TYPE-C-31-M-12; USB-C_SMD-TYPE-C-31-M-12; LCSC C165948
U4: TPSMF05CT1G; SOT-363_L2.0-W1.3-P0.65-LS2.1-BL; LCSC C558443
U5, U6: GT-TC018A-H0375-L1; SW-SMD_L4.7-W3.5-P3.35-EH; LCSC C963235
U7: XDWF-0920-02P; CONN-SMD_XDWF-0920-02P; LCSC C7527581
U8: XT4054K421MR-G; SOT-23-5_L3.0-W1.7-P0.95-LS2.8-BL; LCSC C141405
U9: K2-1102SP-Z4SC-04; KEY-SMD_4P-L6.0-W6.0-P4.50-LS9.0; LCSC C879736

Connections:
+3V3: C2.1, C3.1, C4.1, C5.1, LED2.2 (A), R6.1, U1.2 (3V3), U2.5 (VOUT)
ADC_BATT: R10.2, R11.1, U1.12 (IO8)
BADGE_+3V3: J4.2, J5.A21 (+3.3V), J5.A27 (+3.3V), J5.A33 (+3.3V), J5.A39 (+3.3V), J5.A45 (+3.3V), J5.A53 (+3.3V), J5.B25 (+3.3V), J5.B31 (+3.3V), J5.B36 (+3.3V), J5.B41 (+3.3V), J5.B43 (+3.3V), J5.B54 (+3.3V)
BADGE_RESET: J1.6, J5.B29 (AD[21]), JP2.1 (A)
BADGE_VDD: D4.1 (VDD), J3.2, J5.A5 (+5V), J5.A8 (+5V), J5.A61 (+5V), J5.A62 (+5V), J5.B5 (+5V), J5.B6 (+5V), J5.B61 (+5V), J5.B62 (+5V), KEY2.3
BOOTSEL: U1.27 (IO0), U6.2
BTN_A: J1.5, J5.B30 (AD[19]), U1.23 (IO21)
BTN_DOWN: J1.14, J5.B4 (TDO), U1.7 (IO7)
BTN_TRIGGER: J6.2, U1.6 (IO6), U9.1, U9.2
BTN_UP: J1.15, J5.B2 (TCK), U1.8 (IO15)
CHRG: R9.2, U8.1 (CHRG#)
DOCK_RGB_LED: D4.4 (DIN), U1.25 (IO48)
GND: C1.2, C2.2, C3.2, C4.2, C5.2, C6.2, C7.2, C8.2, C9.2, D4.3 (VSS), J1.1, J3.1, J4.1, J5.A18 (GND), J5.A24 (GND), J5.A30 (GND), J5.A35 (GND), J5.A37 (GND), J5.A42 (GND), J5.A48 (GND), J5.A56 (GND), J5.B3 (GND), J5.B15 (GND), J5.B17 (GND), J5.B22 (GND), J5.B28 (GND), J5.B34 (GND), J5.B38 (GND), J5.B46 (GND), J5.B57 (GND), J6.1, J7.4, KEY1.4, KEY1.5, KEY1.6, KEY1.7, KEY2.4, KEY2.5, KEY2.6, KEY2.7, R1.2, R3.2, R4.2, R5.2, R8.2, R11.2, R12.2, U1.1 (GND), U1.40 (GND), U1.41 (GND), U2.2 (GND), U3.0 (SH), U3.A1 (GND), U3.A12 (GND), U3.B1 (GND), U3.B12 (GND), U4.2, U5.1, U5.3, U5.4, U6.1, U6.3, U6.4, U7.1, U7.3, U7.4, U8.2 (GND), U9.3, U9.4
GPIO1: J1.9, J5.B19 (VIO), U1.19 (IO11)
GPIO2: J1.10, J5.B20 (AD[31]), U1.18 (IO10)
GPIO3: J1.11, J5.B21 (AD[29]), U1.17 (IO9)
I2C_SCL: J1.3, J5.B33 (~C/BE#[2]), U1.5 (IO5)
I2C_SDA: J1.4, J5.B32 (AD[17]), U1.4 (IO4)
IR_IN: J1.13, J5.B7 (~INTB#), U1.22 (IO14)
IR_OUT: J1.12, J5.B8 (~INTD#), U1.21 (IO13)
unnamed: D3.1 (C), KEY2.2
unnamed: D5.1 (C), JP1.2 (B)
unnamed: J7.1, U1.39 (IO1)
unnamed: J7.2, U1.38 (IO2)
unnamed: J7.3, U1.15 (IO3)
unnamed: JP2.2 (B), U1.20 (IO12)
unnamed: LED1.1 (C), R1.1
unnamed: LED2.1 (C), R3.1
unnamed: LED3.1 (C), R9.1
unnamed: LED4.1 (C), R12.1
unnamed: R7.2, R8.1
unnamed: R2.2, U2.3 (EN)
unnamed: R5.1, U3.A5 (CC1)
unnamed: R4.1, U3.B5 (CC2)
POWER_IN: D1.1 (C), D2.1 (C), KEY1.3
RESET: C6.1, R6.2, U1.3 (EN), U5.2
RGB_OUT: J1.2, J5.B60 (~ACK64#)
RPROG: R7.1, U8.5 (PROG)
STAT_LED: LED4.2 (A), U1.26 (IO45)
SV1: J2.1, J5.A3 (TMS), U1.9 (IO16)
SV2: J2.2, J5.A1 (~TRST#), U1.10 (IO17)
SV3: J2.3, J5.A49 (AD[09]), U1.11 (IO18)
SV4: J2.4, J5.A47 (AD[11]), U1.31 (IO38)
SV5: J2.5, J5.A38 (~STOP#), U1.32 (IO39)
SV6: J2.6, J5.A36 (~TRDY#), U1.33 (IO40)
SV7: J2.7, J5.A10 (VIO), U1.34 (IO41)
SV8: J2.8, J5.A9 (RESERVED), U1.35 (IO42)
UART_RX: J1.7, J5.B24 (AD[25]), U1.37 (TXD0)
UART_TX: J1.8, J5.B23 (AD[27]), U1.36 (RXD0)
USB_D+: U1.14 (USB_D+), U3.A6 (DP1), U3.B6 (DP2), U4.6
USB_D-: U1.13 (USB_D-), U3.A7 (DN1), U3.B7 (DN2), U4.5
VBAT: C8.1, C9.1, D1.2 (A), R10.1, U7.2, U8.3 (BAT)
VBUS: D2.2 (A), D5.2 (A), U3.A4 (VBUS), U3.A9 (VBUS), U3.B4 (VBUS), U3.B9 (VBUS), U4.4
VBUS_CHRG: C7.1, JP1.1 (A), LED3.2 (A), U8.4 (VCC)
VDD: C1.1, D3.2 (A), KEY1.2, LED1.2 (A), R2.1, U2.1 (VIN)

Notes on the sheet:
USB
Btn + RGB Led
POWER
ESP32-S3
PCI CONNECTOR
Batt Charger
Breakouts

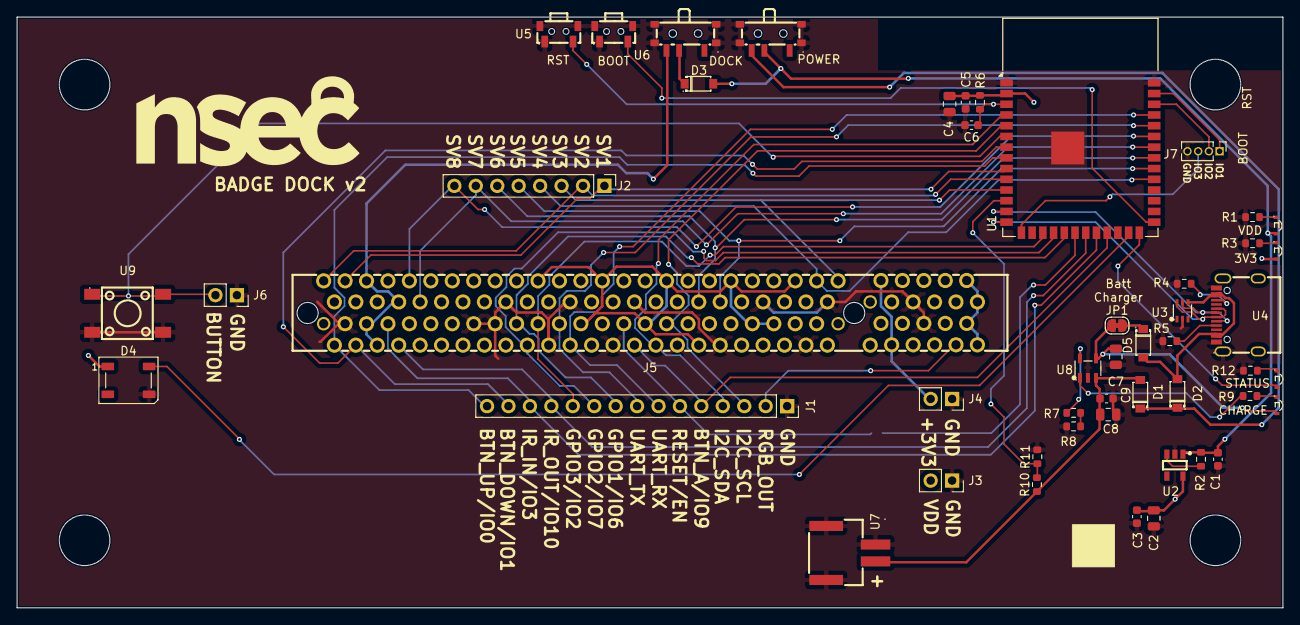
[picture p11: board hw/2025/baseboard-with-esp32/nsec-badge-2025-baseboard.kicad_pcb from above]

Board: 2 copper layers, 150.0 x 70.0 mm, 50 parts (1 on the bottom side), 55 nets.

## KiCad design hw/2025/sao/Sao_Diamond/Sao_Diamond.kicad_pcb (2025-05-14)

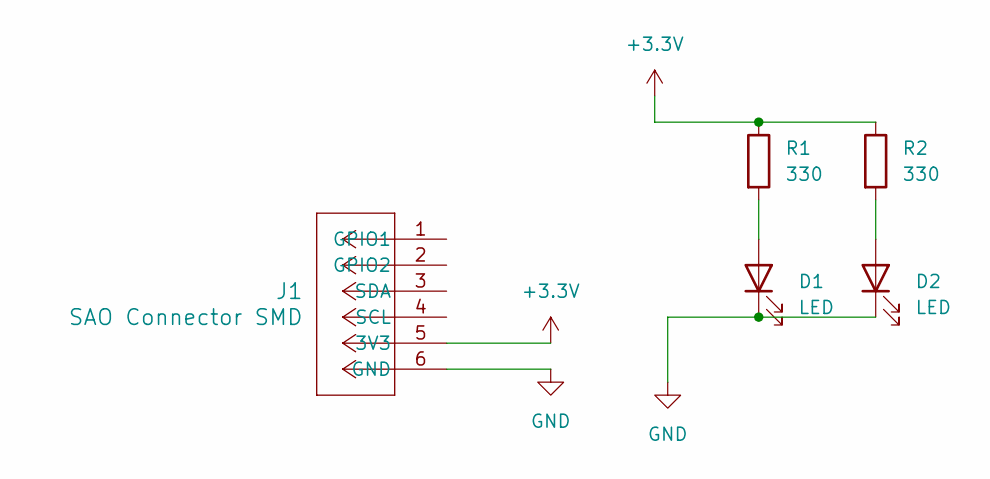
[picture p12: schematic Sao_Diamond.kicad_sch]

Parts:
D1, D2: LED; LED_D3.0mm
J1: SAO Connector SMD
R1, R2: 330; R_Axial_DIN0204_L3.6mm_D1.6mm_P7.62mm_Horizontal

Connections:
+3.3V: J1.5 (3V3), R1.1, R2.1
GND: D1.1 (K), D2.1 (K), J1.6 (GND)
unnamed: D1.2 (A), R1.2
unnamed: D2.2 (A), R2.2

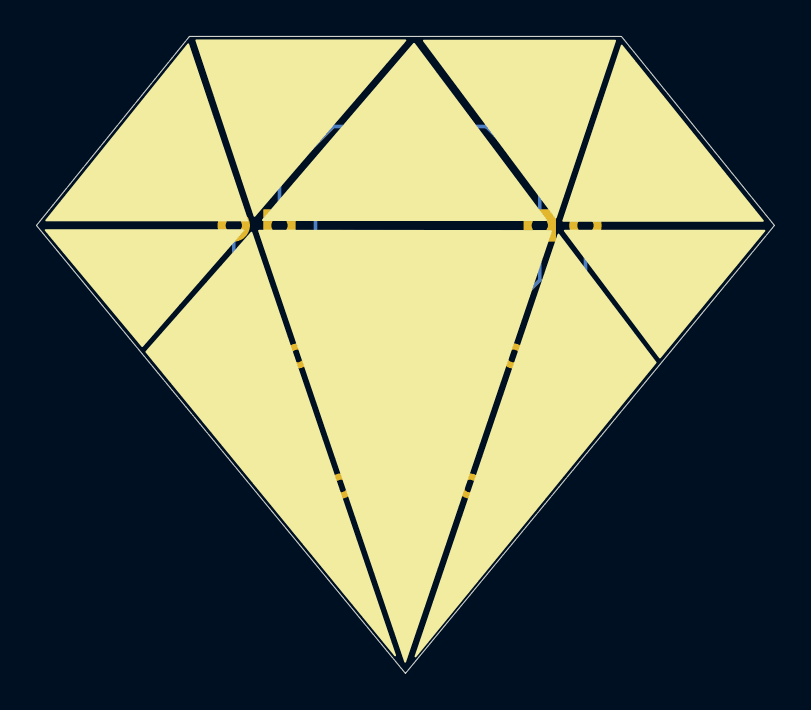
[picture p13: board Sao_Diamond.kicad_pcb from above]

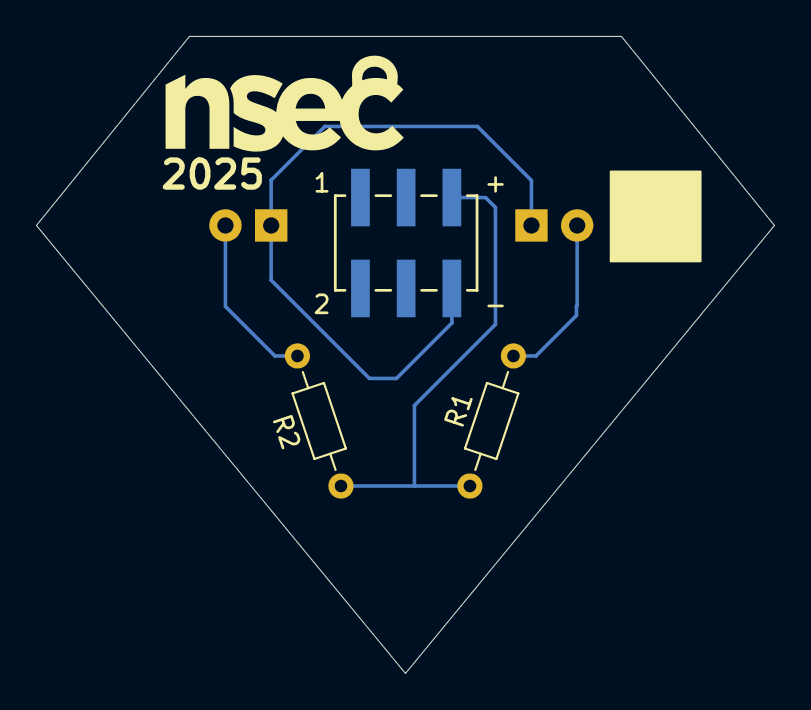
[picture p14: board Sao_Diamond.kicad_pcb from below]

Board: 2 copper layers, 41.0 x 35.4 mm, 5 parts (3 on the bottom side), 4 nets.

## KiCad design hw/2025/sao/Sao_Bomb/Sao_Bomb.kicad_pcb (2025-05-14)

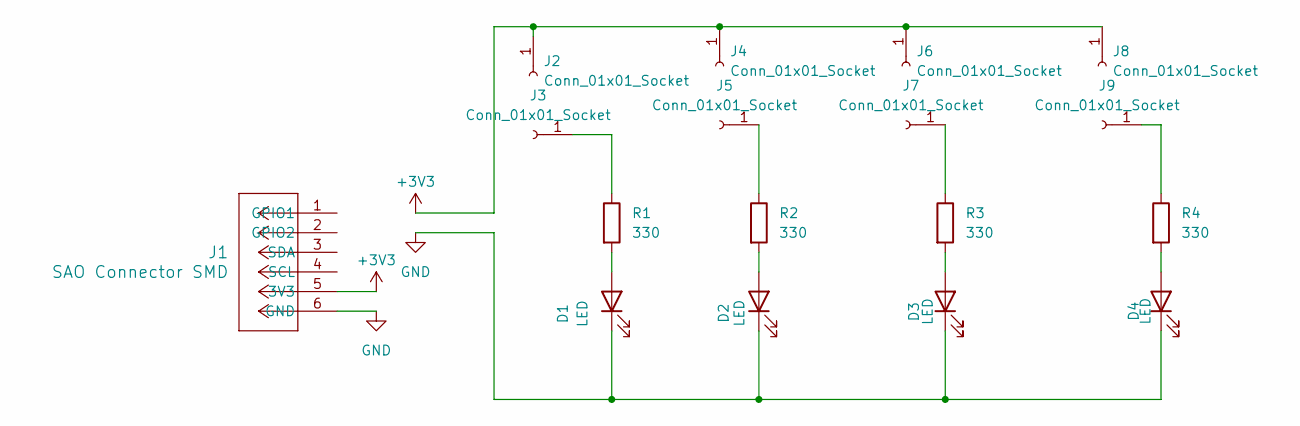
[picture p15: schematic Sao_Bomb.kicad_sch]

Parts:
D1, D2, D3, D4: LED; LED_1206_3216Metric_Pad1.42x1.75mm_HandSolder
J1: SAO Connector SMD
J2, J3, J4, J5, J6, J7, J8, J9: Conn_01x01_Socket; PinSocket_1x01_P1.27mm_Vertical
R1, R2, R3, R4: 330; R_1206_3216Metric_Pad1.30x1.75mm_HandSolder

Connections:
+3V3: J1.5 (3V3), J2.1, J4.1, J6.1, J8.1
GND: D1.1 (K), D2.1 (K), D3.1 (K), D4.1 (K), J1.6 (GND)
unnamed: D1.2 (A), R1.2
unnamed: D2.2 (A), R2.2
unnamed: D3.2 (A), R3.2
unnamed: D4.2 (A), R4.2
unnamed: J3.1, R1.1
unnamed: J5.1, R2.1
unnamed: J7.1, R3.1
unnamed: J9.1, R4.1

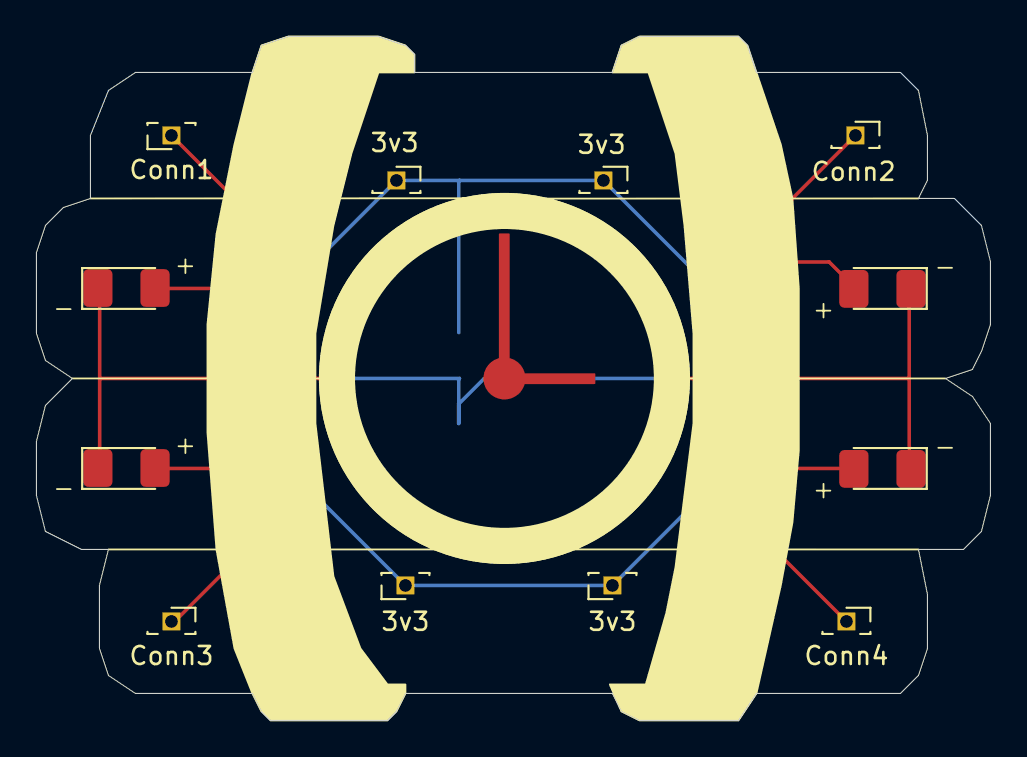
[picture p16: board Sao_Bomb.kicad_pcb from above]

Board: 2 copper layers, 53.0 x 38.0 mm, 17 parts (1 on the bottom side), 10 nets.

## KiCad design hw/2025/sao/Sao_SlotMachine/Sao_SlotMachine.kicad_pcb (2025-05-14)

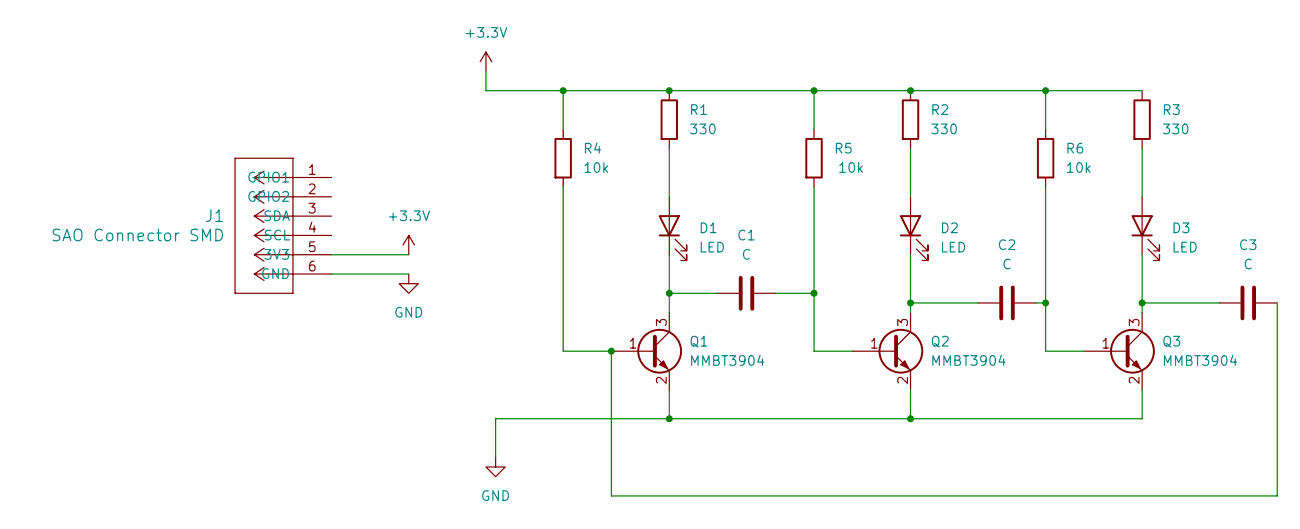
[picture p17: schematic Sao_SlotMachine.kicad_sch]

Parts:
C1, C2, C3: C; C_0402_1005Metric_Pad0.74x0.62mm_HandSolder
D1, D2, D3: LED; LED_0402_1005Metric_Pad0.77x0.64mm_HandSolder
J1: SAO Connector SMD
Q1, Q2, Q3: MMBT3904; SOT-23
R1, R2, R3: 330; R_0402_1005Metric_Pad0.72x0.64mm_HandSolder
R4, R5, R6: 10k; R_0402_1005Metric_Pad0.72x0.64mm_HandSolder

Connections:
+3.3V: J1.5 (3V3), R1.1, R2.1, R3.1, R4.1, R5.1, R6.1
GND: J1.6 (GND), Q1.2 (E), Q2.2 (E), Q3.2 (E)
unnamed: D1.2 (A), R1.2
unnamed: C1.1, D1.1 (K), Q1.3 (C)
unnamed: D2.2 (A), R2.2
unnamed: C2.1, D2.1 (K), Q2.3 (C)
unnamed: D3.2 (A), R3.2
unnamed: C3.1, D3.1 (K), Q3.3 (C)
unnamed: C3.2, Q1.1 (B), R4.2
unnamed: C1.2, Q2.1 (B), R5.2
unnamed: C2.2, Q3.1 (B), R6.2

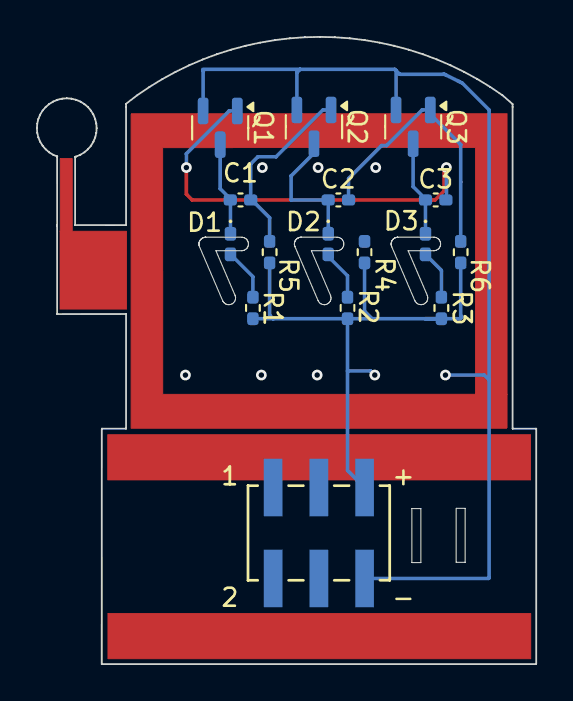
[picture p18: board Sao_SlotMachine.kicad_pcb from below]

Board: 2 copper layers, 27.7 x 34.8 mm, 16 parts (16 on the bottom side), 11 nets.

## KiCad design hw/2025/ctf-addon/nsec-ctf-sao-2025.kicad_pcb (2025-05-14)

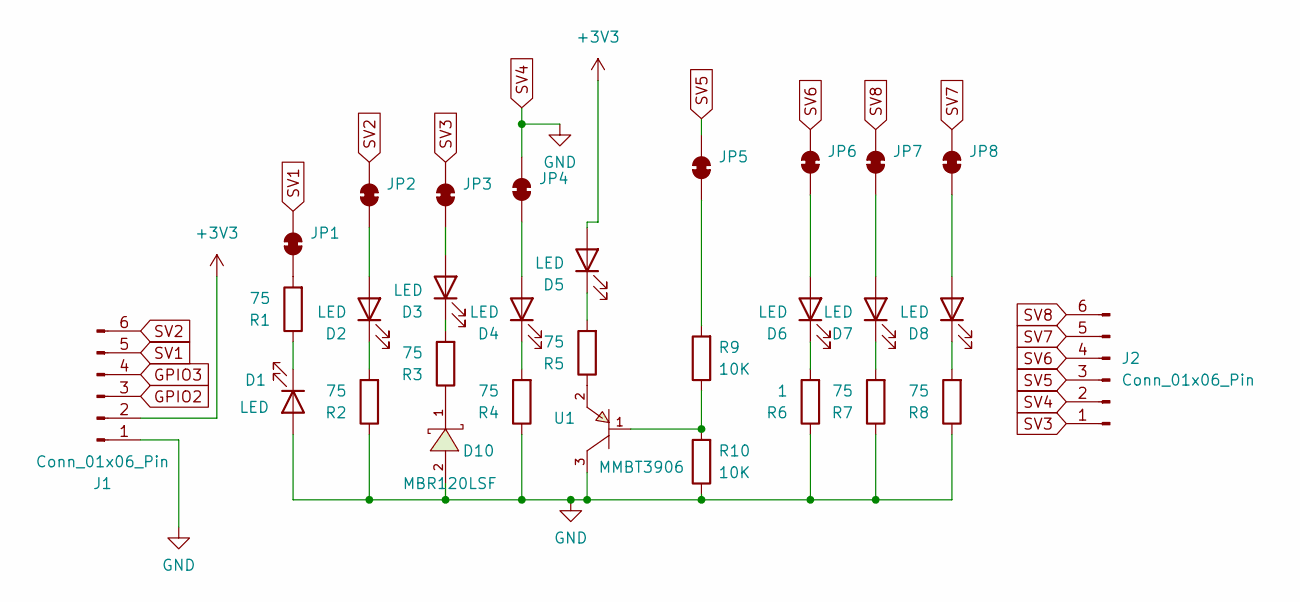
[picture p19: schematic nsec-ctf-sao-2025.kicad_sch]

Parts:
D1, D2, D3, D4, D5, D6, D7, D8: LED; LED_1206_3216Metric_Pad1.42x1.75mm_HandSolder; LCSC C965822
D10: MBR120LSF; SOD-123_L2.8-W1.8-LS3.7-RD; LCSC C130880
J1, J2: Conn_01x06_Pin; PinHeader_1x06_P2.54mm_Vertical
JP1, JP2, JP3, JP4, JP5, JP6, JP7, JP8: SolderJumper_2_Bridged; SolderJumper-2_P1.3mm_Bridged_RoundedPad1.0x1.5mm
R1, R2, R3, R4, R5, R7, R8: 75; R_1206_3216Metric_Pad1.30x1.75mm_HandSolder; LCSC C17987
R6: 1; R_1206_3216Metric_Pad1.30x1.75mm_HandSolder; LCSC C1409
R9, R10: 10K; R_0805_2012Metric_Pad1.20x1.40mm_HandSolder; LCSC C17414
U1: MMBT3906; SOT-23-3_L3.0-W1.7-P0.95-LS2.9-BR; LCSC C111114

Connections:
+3V3: D5.2 (A), J1.2
GPIO2: J1.3
GPIO3: J1.4
unnamed: D1.1 (K), R1.1
unnamed: D2.2 (A), JP2.1 (A)
unnamed: D2.1 (K), R2.2
unnamed: D3.2 (A), JP3.1 (A)
unnamed: D3.1 (K), R3.2
unnamed: D4.2 (A), JP4.1 (A)
unnamed: D4.1 (K), R4.2
unnamed: D5.1 (K), R5.2
unnamed: D6.2 (A), JP6.1 (A)
unnamed: D6.1 (K), R6.2
unnamed: D7.2 (A), JP7.1 (A)
unnamed: D7.1 (K), R7.2
unnamed: D8.2 (A), JP8.1 (A)
unnamed: D8.1 (K), R8.2
unnamed: D10.1 (C), R3.1
unnamed: JP1.1 (A), R1.2
unnamed: JP5.1 (A), R9.2
unnamed: R9.1, R10.2, U1.1 (B)
unnamed: R5.1, U1.2 (E)
SV1: J1.5, JP1.2 (B)
SV2: J1.6, JP2.2 (B)
SV3: J2.1, JP3.2 (B)
SV4: D1.2 (A), D10.2 (A), J1.1, J2.2, JP4.2 (B), R2.1, R4.1, R6.1, R7.1, R8.1, R10.1, U1.3 (C)
SV5: J2.3, JP5.2 (B)
SV6: J2.4, JP6.2 (B)
SV7: J2.5, JP8.2 (B)
SV8: J2.6, JP7.2 (B)

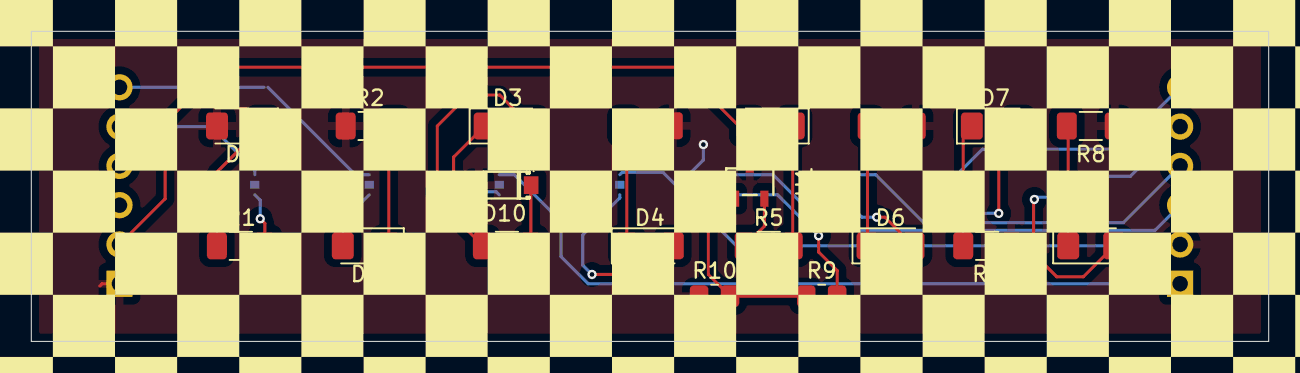
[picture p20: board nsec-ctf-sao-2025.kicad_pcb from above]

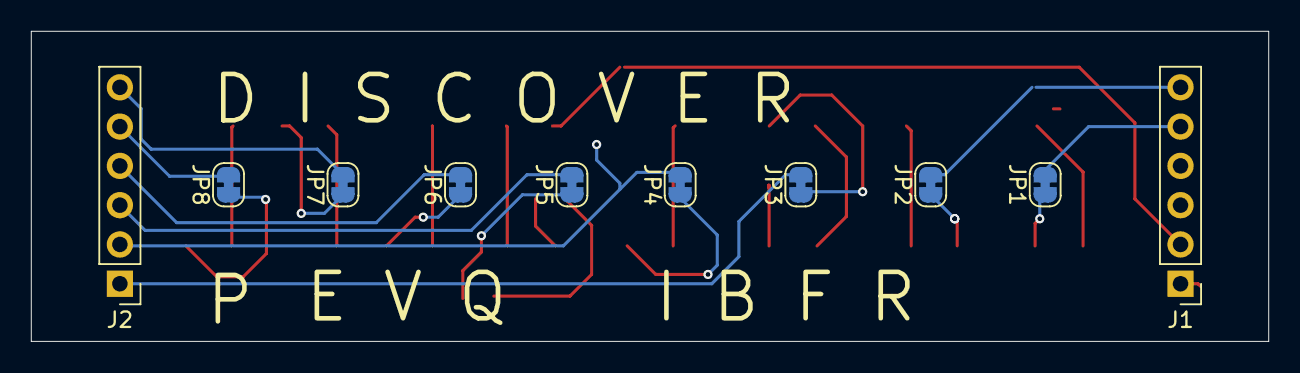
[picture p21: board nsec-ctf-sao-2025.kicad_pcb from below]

Board: 2 copper layers, 80.0 x 20.1 mm, 30 parts (10 on the bottom side), 28 nets.

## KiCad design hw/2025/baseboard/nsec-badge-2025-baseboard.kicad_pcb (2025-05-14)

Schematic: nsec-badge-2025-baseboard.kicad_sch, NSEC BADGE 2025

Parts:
J1: Conn_01x15_Socket; PinSocket_1x15_P2.54mm_Vertical
J2: Conn_01x08_Socket; PinHeader_1x08_P2.54mm_Vertical
J3, J4, J6, J7: Conn_01x02_Socket; PinSocket_1x02_P2.54mm_Vertical
J5: Bus_PCI_32bit_Universal; CONN-TH_EH06003-DAW-DF

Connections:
+3V3: J4.2, J5.A21 (+3.3V), J5.A27 (+3.3V), J5.A33 (+3.3V), J5.A39 (+3.3V), J5.A45 (+3.3V), J5.A53 (+3.3V), J5.B25 (+3.3V), J5.B31 (+3.3V), J5.B36 (+3.3V), J5.B41 (+3.3V), J5.B43 (+3.3V), J5.B54 (+3.3V), J7.2
BTN_A: J1.5, J5.B30 (AD[19])
BTN_DOWN: J1.14, J5.B4 (TDO)
BTN_UP: J1.15, J5.B2 (TCK)
GND: J1.1, J3.1, J4.1, J5.A18 (GND), J5.A24 (GND), J5.A30 (GND), J5.A35 (GND), J5.A37 (GND), J5.A42 (GND), J5.A48 (GND), J5.A56 (GND), J5.B3 (GND), J5.B15 (GND), J5.B17 (GND), J5.B22 (GND), J5.B28 (GND), J5.B34 (GND), J5.B38 (GND), J5.B46 (GND), J5.B57 (GND), J6.1, J7.1
GPIO1: J1.9, J5.B19 (VIO)
GPIO2: J1.10, J5.B20 (AD[31])
GPIO3: J1.11, J5.B21 (AD[29])
I2C_SCL: J1.3, J5.B33 (~C/BE#[2])
I2C_SDA: J1.4, J5.B32 (AD[17])
IR_IN: J1.13, J5.B7 (~INTB#)
IR_OUT: J1.12, J5.B8 (~INTD#)
RESET: J1.6, J5.B29 (AD[21])
RGB_OUT: J1.2, J5.B60 (~ACK64#)
SV1: J2.1, J5.A3 (TMS)
SV2: J2.2, J5.A1 (~TRST#)
SV3: J2.3, J5.A49 (AD[09])
SV4: J2.4, J5.A47 (AD[11])
SV5: J2.5, J5.A38 (~STOP#)
SV6: J2.6, J5.A36 (~TRDY#)
SV7: J2.7, J5.A10 (VIO)
SV8: J2.8, J5.A9 (RESERVED)
UART_RX: J1.7, J5.B24 (AD[25])
UART_TX: J1.8, J5.B23 (AD[27])
VDD: J3.2, J5.A5 (+5V), J5.A8 (+5V), J5.A61 (+5V), J5.A62 (+5V), J5.B5 (+5V), J5.B6 (+5V), J5.B61 (+5V), J5.B62 (+5V), J6.2

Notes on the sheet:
PCI CONNECTOR

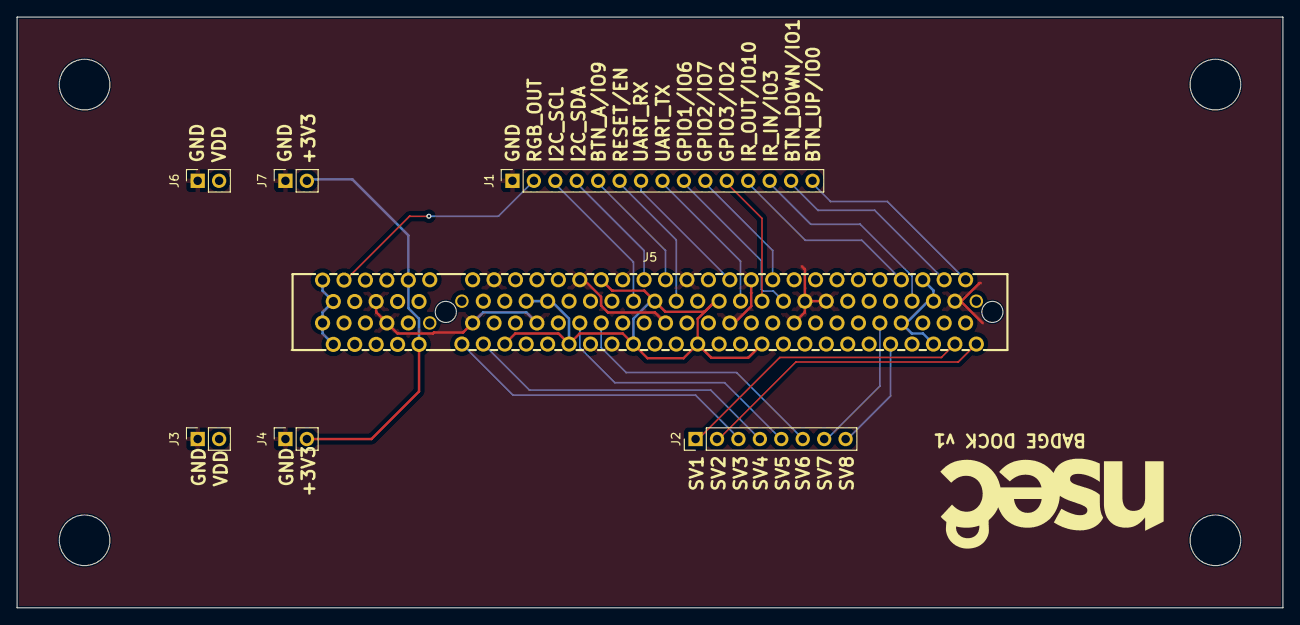
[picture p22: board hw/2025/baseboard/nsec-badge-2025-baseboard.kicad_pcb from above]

Board: 2 copper layers, 150.0 x 70.0 mm, 7 parts (0 on the bottom side), 25 nets.

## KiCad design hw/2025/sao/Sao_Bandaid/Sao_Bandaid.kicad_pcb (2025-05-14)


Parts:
D1: LED; LED_1206_3216Metric_Pad1.42x1.75mm_HandSolder
J1: SAO Connector SMD
R1: 330; R_1206_3216Metric_Pad1.30x1.75mm_HandSolder
R2, R3: 1K; R_1206_3216Metric_Pad1.30x1.75mm_HandSolder

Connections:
+3V3: J1.5 (3V3), R1.1, R2.2, R3.2
GND: D1.1 (K), J1.6 (GND)
unnamed: D1.2 (A), R1.2
unnamed: J1.4 (SCL), R2.1
unnamed: J1.3 (SDA), R3.1



Board: 2 copper layers, 47.0 x 14.0 mm, 5 parts (4 on the bottom side), 5 nets.

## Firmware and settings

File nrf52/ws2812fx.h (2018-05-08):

/*
  WS2812FX.h - Library for WS2812 LED effects.

  This is a C version of the arduino library:
  https://github.com/kitesurfer1404/WS2812FX

  That library use led_effects instead of Adafruit_NeoPixel

  LICENSE
  The MIT License (MIT)
  Copyright (c) 2016  Harm Aldick
  Permission is hereby granted, free of charge, to any person obtaining a copy
  of this software and associated documentation files (the "Software"), to deal
  in the Software without restriction, including without limitation the rights
  to use, copy, modify, merge, publish, distribute, sublicense, and/or sell
  copies of the Software, and to permit persons to whom the Software is
  furnished to do so, subject to the following conditions:
  The above copyright notice and this permission notice shall be included in
  all copies or substantial portions of the Software.
  THE SOFTWARE IS PROVIDED "AS IS", WITHOUT WARRANTY OF ANY KIND, EXPRESS OR
  IMPLIED, INCLUDING BUT NOT LIMITED TO THE WARRANTIES OF MERCHANTABILITY,
  FITNESS FOR A PARTICULAR PURPOSE AND NONINFRINGEMENT. IN NO EVENT SHALL THE
  AUTHORS OR COPYRIGHT HOLDERS BE LIABLE FOR ANY CLAIM, DAMAGES OR OTHER
  LIABILITY, WHETHER IN AN ACTION OF CONTRACT, TORT OR OTHERWISE, ARISING FROM,
  OUT OF OR IN CONNECTION WITH THE SOFTWARE OR THE USE OR OTHER DEALINGS IN
  THE SOFTWARE.
*/

#ifndef WS2812FX_h
#define WS2812FX_h

#include <stdbool.h>
#include "led_effects.h"
#include "random.h"

#define DEFAULT_BRIGHTNESS 50
#define DEFAULT_MODE 0
#define DEFAULT_SPEED 1000
#define DEFAULT_COLOR 0x000000

#define SPEED_MIN 10

#define BRIGHTNESS_MIN 0
#define BRIGHTNESS_MAX 255

/* each segment uses 36 bytes of SRAM memory, so if you're application fails because of
  insufficient memory, decreasing MAX_NUM_SEGMENTS may help */
#define MAX_NUM_SEGMENTS 8
#define NUM_COLORS 3     /* number of colors per segment */

// some common colors
#define RED        0xFF0000
#define GREEN      0x00FF00
#define BLUE       0x0000FF
#define WHITE      0xFFFFFF
#define BLACK      0x000000
#define YELLOW     0xFFFF00
#define CYAN       0x00FFFF
#define MAGENTA    0xFF00FF
#define PURPLE     0x400080
#define ORANGE     0xFF3000
#define ULTRAWHITE 0xFFFFFFFF

#define MODE_COUNT 57

#define FX_MODE_STATIC                   0
#define FX_MODE_BLINK                    1
#define FX_MODE_BREATH                   2
#define FX_MODE_COLOR_WIPE               3
#define FX_MODE_COLOR_WIPE_INV           4 
#define FX_MODE_COLOR_WIPE_REV           5
#define FX_MODE_COLOR_WIPE_REV_INV       6
#define FX_MODE_COLOR_WIPE_RANDOM        7
#define FX_MODE_RANDOM_COLOR             8
#define FX_MODE_SINGLE_DYNAMIC           9
#define FX_MODE_MULTI_DYNAMIC           10
#define FX_MODE_RAINBOW                 11
#define FX_MODE_RAINBOW_CYCLE           12
#define FX_MODE_SCAN                    13
#define FX_MODE_DUAL_SCAN               14
#define FX_MODE_FADE                    15
#define FX_MODE_THEATER_CHASE           16
#define FX_MODE_THEATER_CHASE_RAINBOW   17
#define FX_MODE_RUNNING_LIGHTS          18
#define FX_MODE_TWINKLE                 19
#define FX_MODE_TWINKLE_RANDOM          20
#define FX_MODE_TWINKLE_FADE            21
#define FX_MODE_TWINKLE_FADE_RANDOM     22
#define FX_MODE_SPARKLE                 23
#define FX_MODE_FLASH_SPARKLE           24
#define FX_MODE_HYPER_SPARKLE           25
#define FX_MODE_STROBE                  26
#define FX_MODE_STROBE_RAINBOW          27
#define FX_MODE_MULTI_STROBE            28
#define FX_MODE_BLINK_RAINBOW           29
#define FX_MODE_CHASE_WHITE             30
#define FX_MODE_CHASE_COLOR             31
#define FX_MODE_CHASE_RANDOM            32
#define FX_MODE_CHASE_RAINBOW           33
#define FX_MODE_CHASE_FLASH             34
#define FX_MODE_CHASE_FLASH_RANDOM      35
#define FX_MODE_CHASE_RAINBOW_WHITE     36
#define FX_MODE_CHASE_BLACKOUT          37
#define FX_MODE_CHASE_BLACKOUT_RAINBOW  38
#define FX_MODE_COLOR_SWEEP_RANDOM      39
#define FX_MODE_RUNNING_COLOR           40
#define FX_MODE_RUNNING_RED_BLUE        41
#define FX_MODE_RUNNING_RANDOM          42
#define FX_MODE_LARSON_SCANNER          43
#define FX_MODE_COMET                   44
#define FX_MODE_FIREWORKS               45
#define FX_MODE_FIREWORKS_RANDOM        46
#define FX_MODE_MERRY_CHRISTMAS         47
#define FX_MODE_FIRE_FLICKER            48
#define FX_MODE_FIRE_FLICKER_SOFT       49
#define FX_MODE_FIRE_FLICKER_INTENSE    50
#define FX_MODE_CIRCUS_COMBUSTUS        51
#define FX_MODE_HALLOWEEN               52
#define FX_MODE_BICOLOR_CHASE           53
#define FX_MODE_TRICOLOR_CHASE          54
#define FX_MODE_ICU                     55
#define FX_MODE_CUSTOM                  56

void init_WS2812FX(void);
void service_WS2812FX(void);
void start_WS2812FX(void);
void stop_WS2812FX(void);
void setMode_WS2812FX(uint8_t m);
void setCustomMode_WS2812FX(uint16_t (*p)());
void setSpeed_WS2812FX(uint16_t s);
void setReverse_WS2812FX(bool reverse);
void increaseSpeed_WS2812FX(uint8_t s);
void decreaseSpeed_WS2812FX(uint8_t s);
void setColor_WS2812FX(uint8_t r, uint8_t g, uint8_t b);
void setArrayColor_WS2812FX(uint8_t r, uint8_t g, uint8_t b, uint8_t index);
void setColor_packed_WS2812FX(uint32_t c);
void setArrayColor_packed_WS2812FX(uint32_t c, uint8_t index);
void setBrightness_WS2812FX(uint8_t b);
void increaseBrightness_WS2812FX(uint8_t s);
void decreaseBrightness_WS2812FX(uint8_t s);
void trigger_WS2812FX(void);
void setNumSegments_WS2812FX(uint8_t n);
void setSegment_WS2812FX(uint8_t n, uint16_t start, uint16_t stop, uint8_t mode, uint32_t color,   uint16_t speed, bool reverse);
void setSegment_color_array_WS2812FX(uint8_t n, uint16_t start, uint16_t stop, uint8_t mode, const uint32_t colors[], uint16_t speed, bool reverse);
void resetSegments_WS2812FX();

bool isRunning_WS2812FX(void);

uint8_t getMode_WS2812FX(void);
uint8_t getBrightness_WS2812FX(void);
uint8_t getModeCount_WS2812FX(void);
uint8_t getNumSegments_WS2812FX(void);

uint16_t getSpeed_WS2812FX(void);
bool getReverse_WS2812FX(void);
uint16_t getLength_WS2812FX(void);
uint32_t getColor_WS2812FX(void);
uint32_t getArrayColor_WS2812FX(uint8_t index);

const char* getModeName_WS2812FX(uint8_t m);

#endif

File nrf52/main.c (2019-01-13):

//  Copyright (c) 2017
//  Benjamin Vanheuverzwijn <bvanheu@gmail.com>
//  Marc-Etienne M. Leveille <marc.etienne.ml@gmail.com>
//
//  License: MIT (see LICENSE for details)


#include "ble/nsec_ble.h"

#include <nrf.h>
#include <nrf_error.h>
#include <nrf_gpio.h>
#include <nrf_delay.h>
#include <nrf52.h>
#include <nrf52_bitfields.h>
#include <nordic_common.h>
#include <stdint.h>
#include <nrf_soc.h>

#include "ble/ble_device.h"
#include "battery.h"
#include "battery_manager.h"

#include "buttons.h"
#include "logs.h"
#include "gfx_effect.h"
#include "identity.h"
#include "menu.h"
#include "nsec_conf_schedule.h"
#include "nsec_settings.h"
#include "timer.h"
#include "power.h"
#include "softdevice.h"
#include "status_bar.h"
#include "ssd1306.h"
#include "utils.h"
#include "ws2812fx.h"
#include "nsec_storage.h"
#include "nsec_led_pattern.h"
#include "nsec_warning.h"
#include "nsec_led_ble.h"

#include "images/nsec_logo_bitmap.c"
#include "ble/service_characteristic.h"
#include "ble/vendor_service.h"

static char g_device_id[10];
bool is_at_main_menu = false;

/*
 * Callback function when APP_ERROR_CHECK() fails
 *
 *  - Display the filename, line number and error code.
 *  - Flash all neopixels red for 5 seconds.
 *  - Reset the system.
 */
void app_error_fault_handler(uint32_t id, uint32_t pc, uint32_t info) {
    static int error_displayed = 0;
    uint8_t count = 50;

    if(!error_displayed) {
        char error_msg[128];
        error_info_t *err_info = (error_info_t *) info;
        snprintf(error_msg, sizeof(error_msg), "%s:%u -> error 0x%08x\r\n",
                 err_info->p_file_name, (unsigned int)err_info->line_num,
                 (unsigned int)err_info->err_code);
        puts(error_msg);
        gfx_set_cursor(0, 0);
        gfx_puts(error_msg);
        gfx_update();
        error_displayed = 1;
    }

    init_WS2812FX();
    setBrightness_WS2812FX(64);
    setSpeed_WS2812FX(200);
    setColor_WS2812FX(255, 0, 0);
    setMode_WS2812FX(FX_MODE_BLINK);
    start_WS2812FX();

    while (count > 0) {
        service_WS2812FX();
        nrf_delay_ms(100);
        count--;
    }

    NVIC_SystemReset();
}

static
void nsec_intro(void) {
    for(uint8_t noise = 128; noise <= 128; noise -= 8) {
        gfx_fill_screen(SSD1306_BLACK);
        gfx_draw_bitmap(17, 11, nsec_logo_bitmap, nsec_logo_bitmap_width, nsec_logo_bitmap_height, SSD1306_WHITE);
        nsec_gfx_effect_addNoise(noise);
        gfx_update();
    }
    for(uint8_t noise = 0; noise <= 128; noise += 8) {
        gfx_fill_screen(SSD1306_BLACK);
        gfx_draw_bitmap(17, 11, nsec_logo_bitmap, nsec_logo_bitmap_width, nsec_logo_bitmap_height, SSD1306_WHITE);
        nsec_gfx_effect_addNoise(noise);
        gfx_update();
    }
}

void open_conference_schedule(uint8_t item) {
    menu_close();
    is_at_main_menu = false;
    nsec_schedule_show_dates();
}

void open_led_pattern(uint8_t item) {
    menu_close();
    is_at_main_menu = false;
    nsec_led_pattern_show();
}

void open_settings(uint8_t item) {
    menu_close();
    is_at_main_menu = false;
    nsec_setting_show();
}

void open_warning(uint8_t item) {
    menu_close();
    is_at_main_menu = false;
    nsec_warning_show();
}

void open_battery_status(uint8_t item) {
    menu_close();
    is_at_main_menu = false;
    show_battery_status();
}

#ifdef NSEC_FLAVOR_CTF
menu_item_s main_menu_items[] = {
    {
        .label = "LED pattern",
        .handler = open_led_pattern,
    }, {
        .label = "Settings",
        .handler = open_settings,
    }, {
        .label = "Battery status",
        .handler = open_battery_status,
    }, {
        .label = "Battery Warning",
        .handler = open_warning,
    }
};
#else
static
menu_item_s main_menu_items[] = {
    {
        .label = "Conference schedule",
        .handler = open_conference_schedule,
    }, {
        .label = "LED pattern",
        .handler = open_led_pattern,
    }, {
        .label = "Settings",
        .handler = open_settings,
    }, {
        .label = "Battery status",
        .handler = open_battery_status,
    }, {
        .label = "Battery Warning",
        .handler = open_warning,
    }
};
#endif

void show_main_menu(void) {
    for(uint8_t noise = 128; noise <= 128; noise -= 16) {
        gfx_fill_screen(SSD1306_BLACK);
        nsec_gfx_effect_addNoise(noise);
        gfx_update();
    }
    nsec_identity_draw();
    nsec_status_bar_ui_redraw();
    menu_init(0, 64-8, 128, 8, sizeof(main_menu_items) / sizeof(main_menu_items[0]), main_menu_items);
    is_at_main_menu = true;
}


int main(void) {
#if defined(NSEC_HARDCODED_BLE_DEVICE_ID)
    sprintf(g_device_id, "%.8s", NSEC_STRINGIFY(NSEC_HARDCODED_BLE_DEVICE_ID));
#else
    sprintf(g_device_id, "NSEC%04X", (uint16_t)(NRF_FICR->DEVICEID[1] % 0xFFFF));
#endif
    g_device_id[9] = '\0';

    /*
     * Initialize base hardware
     */
    log_init();
    power_init();
    softdevice_init();
    timer_init();
    init_WS2812FX();
    ssd1306_init();
    gfx_set_text_background_color(SSD1306_WHITE, SSD1306_BLACK);
    nsec_buttons_init();

    /*
     * Initialize bluetooth stack
     */
    create_ble_device(g_device_id);
    configure_advertising();
    nsec_led_ble_init();
    init_identity_service();
    start_advertising();

    nsec_battery_manager_init();
    nsec_status_bar_init();
    nsec_status_set_name(g_device_id);
    nsec_status_set_badge_class(NSEC_STRINGIFY(NSEC_HARDCODED_BADGE_CLASS));
    nsec_status_set_ble_status(STATUS_BLUETOOTH_ON);

    load_stored_led_settings();

    nsec_intro();
    show_main_menu();

    /*
     * Main loop
     */
    while(true) {
        service_WS2812FX();
        nsec_storage_update();
        power_manage();
    }

    return 0;
}

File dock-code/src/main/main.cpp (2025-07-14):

#include <stdio.h>
#include <inttypes.h>
#include "sdkconfig.h"
#include <stdlib.h>
#include "freertos/FreeRTOS.h"
#include "freertos/task.h"
#include "esp_chip_info.h"
#include "esp_flash.h"
#include "nvs_flash.h"
#include "console/console.h"
#include <badge_ssd1306_helper.hpp>

// Depending on which module you want to use, uncomment the appropriate line.
#include "qkd/qkd.h"
//#include "safe/safe.h"
//#include "codenames/codenames.h"





extern "C" void app_main(void) {

    fflush(stdout);

    /* Wait a few seconds before enabling the console. */
    vTaskDelay(2000 / portTICK_PERIOD_MS);

    // Uncomment the module you want to use.
    //cmd_rf(0, NULL);
    //cmd_safe(0, NULL);
    cmd_qkd(0, NULL);

    /* Spin to prevent main task from exiting. */
    while (true) {
        vTaskDelay(1000 / portTICK_PERIOD_MS);
    }
}

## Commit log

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2019-01-06 Replace all tabs with spaces
    [main.c]
2019-01-13 Start refactoring of display management
    use display abstraction layer display.h to assign the correct screen at
    compile time.
    The graphics function were moved to gfx_effect instead of being specific to the display
    [main.c]
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2019-01-24 Add UART driver for nrf52
    This patch makes the nrf52 able to output some things on the UART that
    is connected to the stm32. Since blackmagic on the stm32 is configured
    to act as an USB-UART device, we are able to see the output using a
    terminal emulator on the dev machine. For reference, this is what I
    used to test:
    $ picocom --imap lfcrlf --baud 38400 /dev/ttyACM1
    I used 38400 baud, because that is the default of the usbuart module of
    blackmagic. But we can crank it up once we see that it works well.
    I added some traces in the buttons code, as an example that doesn't send
    too much data.
    [main.c]
2019-01-25 Fix unused label warning when building with brain board
    When building in this mode, the end_refresh label is unused. Wrap it in
    an ifdef to avoid a warning.
2019-01-25 Fix case of gfx functions
    There is a mismatch of case (snake_case vs camelCase) for some
    functions. It is not only cosmectic, some functions call
    ssd1306_drawPixel, while the real function is called ssd1306_draw_pixel.
    My guess is that the functions that use the wrong name are not actually
    used. So the compilation passes (giving some implicit declaration
    warnings), and those callers are garbage collected during linking, so
    there is no undefined reference.
    It's better to just fix the warnings and use the right names.
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2019-01-31 Revert "Added new team members to NSEC 2019 credits."
    This reverts commit feeee67fe2f0f80bbcd69b08f953c8fd4ea6d5e1.
    [main.c]
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2019-02-08 Add minimal new status bar
    We still need to update the PNG and the reposition the stuck at the correct place
    [main.c]
2019-02-10 Fix compilation error with gcc 5.4.0
    Fix:
    Compiling file: ST7735.c
    src/drivers/ST7735.c:81:1: error: missing braces around initializer [-Werror=missing-braces]
    nrf_pwm_values_individual_t seq_values[1] = {0};
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2019-02-13 Add function to suspend button handler
    rework a little the structure of button handler to be able to desactivate them
    [main.c]
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2019-02-23 Use Python 3 for all Python scripts
    The gen_image script is currently broken for Python 2. Force all the
    scripts to use Python 3.
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2019-02-28 Set neopixel count to 15 and fix hardcoded value in pattern library
    [ws2812fx.c, ws2812fx.h]
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2019-03-05 Add CLI over UART
    This patch adds CLI functionality over UART (over USB) using Nordic's
    CLI module.
    The UART is now completely managed by the CLI, we should not try to read
    or write from it directly. The existing uart support is kept for the
    flash mode, but it should not be used anywhere else.
    It usually does not work right after flashing the program. Power cycle
    the badge, then use:
    picocom --baud 115200 /dev/ttyACM1
    [main.c]
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2019-03-17 Persist display brightness
    The persistency layer is really not as good as i want it but for now
    the time is missing to do something better with the external flash.
    So the brightness is stored with the led settings... until we refactor
    that part of the code. Sorry not sorry
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2019-03-17 Change dfu-util example command
    The `:leave` makes the stm32 exit the bootloader mode and go in application (blackmagic) mode. The --reset flag doesn't do anything useful.
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2019-03-31 Fix bug in nrf_ringbuf, fix UART hang
    There is a bug in the nrf_ringbuf implementation in the version of the
    SDK we use. nrf_ringbuf_alloc sometimes miscalculates the amount of
    available buffer, which leads to a UART hang.
    1. rx_try tries to allocate 255 bytes using nrf_ringbuf_alloc.
    2. nrf_ringbuf_alloc returns a length of 255 bytes, even though less is
    available.
    3. the following nrf_ringbuf_put fails, because we pass it a length of
    255 bytes, but it determines (correctly) that this is more than the
    available buffer space. When failing, it doesn't unlock the write lock
    of the ring buffer.
    4. The next rx_try then fails to alloc, and doesn't call nrf_drv_uart_rx
    to re-enable the receive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
2019-04-07 Process battery manager only in home menu application
    The battery manager refreshes the batter status that causes the battery
    icon to be redrawn. This may interfere with UI of other running
    applications, so it is better to be done only in the default home menu
    application.
    [main.c]
2019-04-07 Prevent button event to be queued when the mode zombie is activated
2019-04-07 Patches to stabilize uart
    This commit contributes two patches to the Nordic SDK that seem to
    stabilize the CLI over UART greatly. It also adds a script I used to
    stress test the UART (details for this are in comments in the script).
    1. Patch fix-uart-error-handling.patch
    Observed behavior: For some reason, after a while of typing manually in
    the CLI, I inevitably get an overrun condition. This means that the
    6-bytes hardware rx fifo is already full when we receive another byte.
    It is not clear to me why this happen, as I do not send a lot of data at
    a high rate, but in any case we must be able to recover when this
    happens. After an overrun, the UART kept reporting an overrun forever.
    F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
2019-04-11 Soldering track on nrf
    After the soldering introduction (5s) the flags are displayed at the screen
    Flag #1: The flag is always there, you can see it as soon as your screen is working
    Flag #2: The flag is printed if the external flash with the flag is soldered
    Flag #3: The user need to press the correct button 10 times in row to print the flag
    The buttons to press are randomly selected
    [main.c]
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2019-04-21 Add basic ledctl command and some implementation to start brightness and reverse
    [ws2812fx.c, ws2812fx.h]
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2019-04-22 Generate different external flash files per flavor
    We will want different external flash contents per flavor. Currently,
    the external flash files (binary file and header) are not rebuilt when
    rebuilding two flavors in a row like:
    $ make FLAVOR=ctf
    $ make FLAVOR=conf
    Ideally, we would have a source directory and multiple, separate build
    directories. But we don't have that, so the next best thing I can think
    of is to generate separate files per flavor. This way, it's easier to
    avoid including a header file generated for the wrong flavor.
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2019-04-22 Add persitence revision
    Also fix persistencty paddig size. This is pain to manage btw
    Fix color settings call
    [ws2812fx.c]
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2019-04-22 Add identity service to the scan response, fix the scan response
    [main.c]
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2019-05-02 Add screen settings menu
    The screen settings menu adds a "Screen fix" entry to switch between the
    Green and Red tab screen models.
    Default is Green tab except for the soldering flavor which is Red tab.
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2019-05-04 Fix sleep timeout in submenus
    [main.c]
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2019-05-05 Fix menu scrolling bugs, reduce number of unnecessary complete redraws
    This patches makes us handle better the case where we are at the topmost
    item and press up. Before this patch, the result is that the last item
    (now selected) is drawn at the top of the screen, the rest of the menu
    being blank. After this patch, the last item (now selected) will drawn
    at the bottom of the screen, with the preceding items visible.
    It also fixes a bugs instances where we would redraw unnecessarily the
    whole screen. For example, when pressing up with the topmost item
    selected or pressing down with the bottommost item selected, we don't
    need to redraw everything if the menu entirely fits on one page.
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2019-05-08 Wait for two button presses to exit snake game
    The first button press is usually the one that is done to avoid
    collision. Add another one to avoid the impression that the game
    automatically exists after a collision.
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2019-05-09 Change my email address
    The current one is too long and spills over the right hand side menu.
2019-05-09 Fix led pattern unlock menus
    Following commit
    1cfacc3c9 ("Implement menu scrolling per page")
    the LED unlock menus are broken. Fix it by handling a bit better the
    boundary conditions of the menu drawing code.
2019-05-10 Fix erroneous wrapping in text box
    This fixes a bug where the last line of a text box page would be
    invisible.
    To reproduce at the previous commit, try to open the second talk of the
    second conference day, titled "Cybersecurity vs the world".
    The problem is that the first line is "Cybersecurity vs the world\n".
    That is, 26 characters plus the trailing \n. The text box is able to
    show 26 characters. When the "d" of "world" is printed, the gfx code
    does some wrapping because the current line is full, it moves the cursor
    to the second line. We then print the trailing \n, which moves the
    cursor to the third line. We are now about to print the second line, at
    the position of the third line.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
2020-02-02 Partial port to SDK16
    This commit ports a good part of the code to SDK 16. There are some
    know limitations:
    - The power module is not initialized, so the external DCDC circuitry is
    not used.
    - Everything BLE-related is commented out.
    - The config is set up to use the internal RC oscillator, not the
    external crystal.
    [main.c]
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2020-02-17 ws2812fx: abort if already initialized
    The `init` static variable in init_WS2812FX is currently never set to
    true, so it's kind of useless right now. Set it to true, but also
    just assert that we don't try to initialize the module twice, as that
    would be a logic error that should be fixed.
    [ws2812fx.c]
2020-02-17 ws2812fx: remove RESET_RUNTIME before allocation
    The call to RESET_RUNTIME (which uses the `fx` variable) in
    init_WS2812FX happens before the `fx` variable is initialized. It
    causes us to try to write at some unexpected place in memory. Clearly,
    it does not cause a crash, but it's not useful either, so remove it.
    Note that there is another call to RESET_RUNTIME lower in the function.
    [ws2812fx.c]
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2020-02-19 Enable NeoPixels
    Initialize the code that controls the ws2812/NeoPixels.
    For testing, I've made the "main" force some effect settings. Of
    course, it will have to be removed eventually.
    It works (the LEDs light up), but it seems to me like the pattern is
    going a bit fast, there might be some timing problems.
    [main.c]
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2020-02-19 Add malloc failed hook
    Add a handler that calls our app_error_fault_handler if FreeRTOS' malloc
    ever fails.
    [main.c]
2020-02-19 Enable stack overflow check
    Enable FreeRTOS' feature to check for potential stack overflows whenever
    it swaps the current task.
    [main.c]
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2020-03-03 Fix conf flavor build
    [main.c]
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2020-03-10 Fix race condition when setting neopixel settings
    There is currently a possibility that changing the led colors through
    the menu causes the UI to freeze.
    This is because we are calling setArrayColor_packed_WS2812FX, which
    eventually calls, setBrightness_WS2812FX, which calls
    nsec_neoPixel_show, and then show_with_PWM. While this happens, the
    Neopixels task keeps calling service_WS2812FX, which also ends up
    calling show_with_PWM. Having two tasks configuring and using the PWM
    device at the same time causes the UI task to block indefinitely waiting
    for the PWM "end" event.
    Only one task should be directly using the PWM. Therefore, remove the
    call to nsec_neoPixel_show from setBrightness_W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
    [ws2812fx.c]
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2021-01-09 Initialize UART in the main task to avoid weird race conditions
    [main.c]
2021-01-10 Drop the app_main() to avoid conflicts with 'main' component
    [main.c]
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2021-03-01 Remove infinite loop at end of app_main
    We currently have an infinite loop at the end of app_main, which is not
    necessary. If we let it finish, it goes back to the main_task function,
    in file esp-idf/components/freertos/port/port_common.c. It then does
    `vTaskDelete(NULL)`, meaning the task deletes itself. The remaining
    tasks we have created keep doing their own thing.
    This does not have an effect today though, because the code is stuck in
    another infinite loop, in rpg_control_take.
    [main.c]
2021-03-02 Make main file C++
    Move main.c to main.cpp, so it's C++.
    This requires adding extern "C" in buttons.h, since we now have a C++
    source file (main) using the buttons subsystem, implemented in C.
    It is also necessary to add extern "C" to app_main, so that the runtime
    that wraps our code still finds the app_main symbol (that doesn't
    prevent using C++ stuff in that function though).
    [main.cpp]
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2021-03-21 Move console init after the graphics, avoiding mixing console banner and graphics logs.
    [main.cpp]
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2021-04-17 exporting C buzzer functions for use with C++
    [main.cpp]
2021-04-17 Fixed buzzer crash when the note is 0 + slight perf improvement by increasing buzzer task priority
    [buzzer.c, main.cpp]
2021-04-17 moved wifi init to the console task to avoid blocking badge boot
    [main.cpp]
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2021-04-19 Change buzzer component API to allow music control from outside
    [main.cpp]
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2021-04-25 Fix the 10th flag from being optimized away
    [main.cpp]
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2023-01-25 generated proposed factory gerber for Rizome (silkscreen still missing)
    [BOM.xlsx, BOM_JLCSMT.xlsx, confBadgeV1.brd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]
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2023-03-03 Updated design from artists
    Still missing fill on Conf-badge top silkscreen
    waiting on bottom silkcreen
    [confBadge-04-front.dxf, confBadge-05-back.dxf, confBadgeV1.brd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]
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2023-07-19 Final silkscreen approved by design + via and holes for stiffner on CTF
    [BOM.xlsx, BOM_JLCSMT.xlsx, bom.csv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]
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2023-07-19 remove vias under stiffner-hole
    recommendation from factory as it might impact the aesthetic of the soldermask
    [version4.brd]
2023-07-19 reduce stiffner hole size to 1mm as recommended by factory
    [version4.brd]
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2023-07-19 Updated challenge. QR Code was wrong. Generated new silkscreen-bottom layer
    [version4.brd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]
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2023-07-19 wip neopixels, issue with `gpio_matrix_out`
    [main.cpp]
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2023-07-19 Fix a few issues with mesh network code: 1) persistent node addresses chosen randomly on first boot 2) persistent sequence numbers to fix issue with replay protection
    [main.cpp]
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2024-01-26 first import
    not working yet.. need to initialize
    [main.cpp]
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2024-03-20 Clean-up: missing namespace close comment
    [config.hpp]
2024-03-20 Fix: ctf firmware build
    * Add the missing variables in the components CMakeLists.txt files
    * Vendor the 'mdns' and 'esp-modbus' components
    * Remove the incompatible metadata in mdns/idf_component.yml
    [main.c]
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2024-03-22 Bug Fix - Rename "button" folder to avoid conflict with "espressif__button" component (#452)
    * button: rename folder to avoid conflict with "espressif__button" component
    When adding the "espressif/button" component, build error occured.
    Two different errors are reported (depending how the component is added).
    Error 1:
    CMake Error at C:/Users/<username>/.platformio/packages/framework-espidf/tools/cmake/component.cmake:479 (add_library):
    Target "__idf_button" links to itself.
    Error 2:
    CMake Error at C:/Users/<username>/.platformio/packages/framework-espidf/tools/cmake/component.cmake:250 (message):
    ERROR: Cannot process component requirements. Multiple candidates to
    satis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
    [watcher.cpp]
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2024-04-03 badge-network: use the esp-idf interfaces to setup communication
    A `uart_interface` class is added to wrap the ESP-idf uart SDK.
    It makes use of some additional scaffolding included as part of this
    change, namely a basic logging class based around libfmt and a number of
    exception handling helpers.
    It seems that variables that are declared as part of `globals.cpp` are
    ignored. I am not sure why, but I am guessing an over-eager
    linker (or perhaps an option like no-as-needed is being passed).
    I have not investigated that behaviour yet. For the moment, the
    declaration of `badge` is moved to the entry point's translation unit
    which seems to work around the problem since it prevented the
    initia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
    [board.hpp, config.hpp, uart_interface.cpp]
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2024-04-14 Upgrade PIO espressif32 platform to 6.6.0
    This fixes a bug with components that include a recent
    'idf_component.yml', it also updates ESP-IDF to v5.2.1.
    Delete the 'modbus' and 'mdns' components that were vendored as a
    workaround, they are now pulled during the build.
    [main.c]
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2024-04-21 Fix: strip animator: handle progress bar decrease transitions
    The progress bar animation assumed that it could only move forwards.
    However, it can effectively go backwards when a pairing attempt fails
    and is retried before going through an "idle" animation cycle.
    [config.hpp, strip_animator.cpp]
2024-04-21 Temporary workaround for badge pairing bug
    [config.hpp]
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2024-04-24 Move button callback registration to the button watcher
    Move the button handling logic to the watcher. This allows the re-use of
    existing C++ utilities and configuration files. It also completely
    eliminates the need for a task.
    The button SDK already makes use of the timers in task mode[1] which
    makes it safe to invoke non-trivial callbacks from the button handling
    code.
    The watcher listens for BUTTON_PRESS_DOWN instead of the equivalent 'UP'
    event. Overall, it gives a snappier feel when cycling the animations
    since the cycling occurs on the press down rather than the release of
    the button.
    https://github.com/espressif/esp-iot-solution/blob/b2c33a0f72c0d4b968a72a3da0de8d8e3d29db83/compone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
    [watcher.cpp]
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2024-04-27 Fix: buttons sometimes not properly initialized
    It seems that FreeRTOS and/or the ESP-IDF SDK are not completely
    initialized before entering app_main(). Since the badge object is
    global, it's constructor runs before the control is handed over to
    app_main().
    The badge instance is moved within the scope of app_main() which causes
    the initialization to happen within a proper FreeRTOS task (and not the
    idle task, if I understand the FreeRTOS code correctly).
    The periodic tasks are launched explicitly by calling badge::start()
    since some of the code relies on a global `the_badge` pointer being
    initialized. Starting the tasks as part of the badge's constructor would
    race with the publication of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
    [strip_animator.cpp, watcher.cpp]
2024-04-28 Enable console on USB
    Unfortunatly the 'console' module provided by the ESP-IDF framework as
    well as the logging system are tied to the default console configured in
    sdkconfig. This means I won't be able to send the logging to UART0 and
    have the console on the USB port without re-implementing the 'console'
    module which I don't plan to do.
    We will have to disable logging in the production firmware so it doesn't
    interfere with the console.
    [console.cpp]
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2024-04-30 Console tweaks
    Lower the logging level of statements inside the 'cmd' component to
    debug so they don't overwrite the console in default builds. Add color
    reset to the prompt to clear leftover color from logging statements.
    Update the splash screen for 2024.
    [console.cpp]
2024-04-30 Add system commands
    Currently implemented are 'reboot' and 'factory_reset'.
    [cmd_sys.cpp, console.cpp]
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2024-05-05 Clear the leds on soft reboot
    When using 'esp_restart()' to do a soft reboot, the leds stay powered
    and thus retain the last frame until the badge is either hard reset or
    reboot in the 'conf' firmware.
    Clear the leds before calling esp_restart().
    [cmd_sys.cpp, strip_animator.cpp]
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2024-05-05 config: set specific module logging level to error
    For the release version, only display the error on the serial console.
    [config.hpp]
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2024-05-05 Add encrypt/decrypt reversing challenge
    [console.cpp]
2024-05-05 Revert "idle" social level display pattern"
    I agree we should find a pattern that is easier to see with the shield
    but some people are sensitive to strobing lights and this pattern is
    pretty harsh.
    This reverts commit 99ca9669132e27770ccdcb4301bd8d84d7bf388d.
    [strip_animator.cpp]
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2024-05-07 Increase the stack size of the badge task
    During testing, we noticed that during 'pairing' the network master
    (leftmost in the chain) would sometimes crash with a stack overflow.
    For now, double the stack size of the badge task.
    [config.hpp]
2024-05-07 Fix: strip-animator: color cycle animations freezing
    Some of the longer color cycle animations freeze because of an overflow
    in the animation system. This overflow occurs because we are running the
    animation system at a higher framerate than last year's badge.
    Fortunately, we can now afford to store the tick count on a whole 16-bit
    integer!
    [strip_animator.cpp]
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2024-05-08 Add a 'clear' command to the console
    Add a 'clear' command to reset the console and print the banner.
    [console.cpp]
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2025-01-26 Remove dependencies to reaction_time and reverse
    [console.cpp]
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2025-03-21 various fixes and formatting
    [console.cpp]
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2025-04-01 strip_animator: use number LEDs assigned to animation instead of total number
    The existing strip animator logic assume a certain maximum number of LEDs.
    To ensure the existing code is not broken, use the total number of LEDs that
    are included in the animation instead of the total number.
    [strip_animator.cpp]
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2025-04-08 strip_animator: add api call to display clearance level
    Add support to display the clearance level on the LED.
    [strip_animator.cpp]
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2025-05-01 Refactor. fixed bugs, logging, api on badge
    [board.hpp, config.hpp, dock_detector.cpp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]
2025-05-01 Badge - cleanup and update (#576)
    * strip_animator: remove unused code
    Removed unused code from the 2023/2024 strip animator badge code.
    * strip_animator: add specific logger config
    Add support to be able to control the logging capability of the
    strip animator individually.
    * config_store: fix spacing alignment
    * config: define "social level check" field name
    Add "social level check" field name to use in the persistence module.
    * config_store: add "social l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
    [board.hpp, config.hpp, console.cpp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]
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2025-05-03 Fixed non-serial delay output and visual screen aids for qkd track (#580)
    * Fixed non-serial delay output and visual screen aids for qkd track
    * fixing comments on pr
    [qkd.cpp]
2025-05-03 Broken code for IR interface
    [config.hpp, ir_interface.cpp]
2025-05-03 Bring back log level to ERROR
    [config.hpp]
2025-05-03 Add jitter for when people press at the same time
    [config.hpp]
2025-05-09 timing fix with qkd dock speed of 30ms and vtaskdelays
    [qkd.cpp]
2025-05-12 adding missing unlocksafe command as well
    [console.cpp]
2025-05-12 Keeping timings equal for each reboot
    [cmd_sys.cpp]
2025-05-14 HW 2025 (#590)
    * Initial Kicad project
    * v0.1
    * PCI 120 pin connector instead of PCIe 1x
    * v1 of prototype
    * Adds BOM, CPL, Gerbers, replace IR components due to stock
    * IBom
    * Schematic PDF
    * Minor fixes in traces
    * Baseboard first version
    * small fix on traces, fix Q1 rotation
    * added test firmware
    Test firmware for main peripherals. This is used to validate the first prototype from the manufacturer
    * Baseboard v1
    * prototype v2
    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
    [BOM-Sao_Bandaid.csv, BOM-Sao_Bomb.csv, BOM-Sao_CashBag.csv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]
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
